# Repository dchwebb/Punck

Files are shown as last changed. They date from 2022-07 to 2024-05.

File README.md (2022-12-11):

# Punck
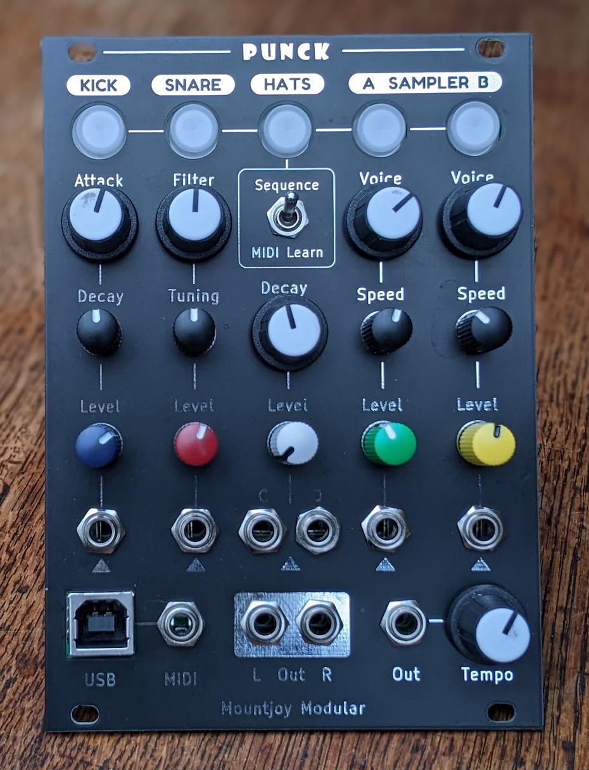
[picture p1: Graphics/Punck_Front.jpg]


Overview
--------

- Audio Demo with Kick, snare and hi hats: [Punck.wav](https://raw.githubusercontent.com/dchwebb/Punck/master/Drum_Sequences/Punck.wav)
- Audio Demo with all voices and samples: [Punck2.wav](https://raw.githubusercontent.com/dchwebb/Punck/master/Drum_Sequences/Punck2.wav)

Punck is drum machine designed for use with Eurorack modular synthesizers. Its five primary voices are Kick, Snare, High Hat and two sample playback channels. In addition Toms and Claps voices are available via MIDI.

It features a built-in drum sequencer with five patterns each with up to 4 bars in length and either 16 or 24 beats per bar.

Voices can be triggered via front panel illuminated buttons, gate input, USB MIDI, serial MIDI and the drum sequencer. All trigger modes are available simultaneously.

Samples are stored on 32MB of internal Flash memory. This storage space is made available as a standard USB drive, requiring no external drives or SD cards.

A browser-based editor allows drum sequences to be entered graphically and detailed parameters of internal voices to be edited. A MIDI mapping facility provides access to different articulations of voices and different samples for the sampler tracks.

Audio DSP
---------

### Kick
The kick drum is modelled on a Roland TR-808 kick. This is generated in five phases, the first three providing an initial steep ramp and discontinuity for the 'click', a fast sine wave at 130Hz and then a slowly decelerating sine wave starting at 60Hz. A potentiometer-controlled 2-pole low pass filter softens the attack and a decay control adjusts the rate at which the level is reduced.

### Snare
The snare is formed of 3 pitched sine wave partials representing the body of the drum and a noise component representing the snare. The partials form the first three modes of vibration of the body. The initial frequency is potentiometer-controlled and the next two partials pitched at multiples of 1.588 and 1.833. The noise component is derived from two random number readings (left and right) and has a decay rate separate from the overall volume envelope. A potentiometer-controlled 2-pole low pass filter attenuates the high frequencies.

### Hi hat
The hi hat consists of 6 square waves with varying rates and levels of frequency modulation. In addition a stereo noise component is used at the beginning of the note. Separate 2-pole high and low pass filters use different ramp envelopes to increase the frequency of the HP filter and reduce the frequency of the LP filter as the note sustains. The decay of the noise and FM partials are separately configurable. When a range of MIDI notes is used to control the hi hat each note will result in a successively more 'open' hi hat sound.

### Sampler A and B
Two independent sample playback voices are provided. These play wave files (8, 16, 24 or 32 bit) stored in the internal flash storage. Each sampler can only play a single sample at a time allowing a maximum of two simultaneously playing voices. Each sampler has a speed control allowing a playback range of 0.5 - 1.5 original speed. Base playback speed is normalised to 48kHz from the original sample rate.

The sample's file name determines the bank (A or B) and index of the sample. Optionally adding suffix '.vNN' to the sample name will set the initial volume of the sample where NN is a value from 0 - 200% and 100% is the original sample level. Eg naming a sample 'B3crash.v150.wav' will make it the 3rd sample on bank B and will play at 150% of its original level.

### Toms
The Toms voice has no UI but is accessible from MIDI and the internal sequencer. An initial fast ramp is followed by a decelerating sine wave. Allocating multiple MIDI notes to playback will allow a range of pitches to be mapped over the MIDI notes.

### Claps
The Claps have no UI but are accessible from MIDI and the internal sequencer. Four 'claps' are played at slightly varying intervals with a sustained phase at the end of the fourth. Each clap is formed of band-pass filtered noise with a center frequency of 1250Hz and a Q of 3.

### Reverb
The reverb engine is derived from Geraint Luff's design: [Signalsmith Audio](https://signalsmith-audio.co.uk/writing/2021/lets-write-a-reverb/). This divides the stereo dry audio into 8 channels which then pass through various diffusion stages followed by a feedback mixer. The diffusion stages use short delay lines and a Hadamard mixing matrix to create a short diffused reverb. The feedback mixer uses longer delays to spread the diffusion channels. The 8 reverb channels are then mixed down to stereo and blended with the dry signal. A 2-pole Low pass filter is used at the input to control high end.

Architecture
------------

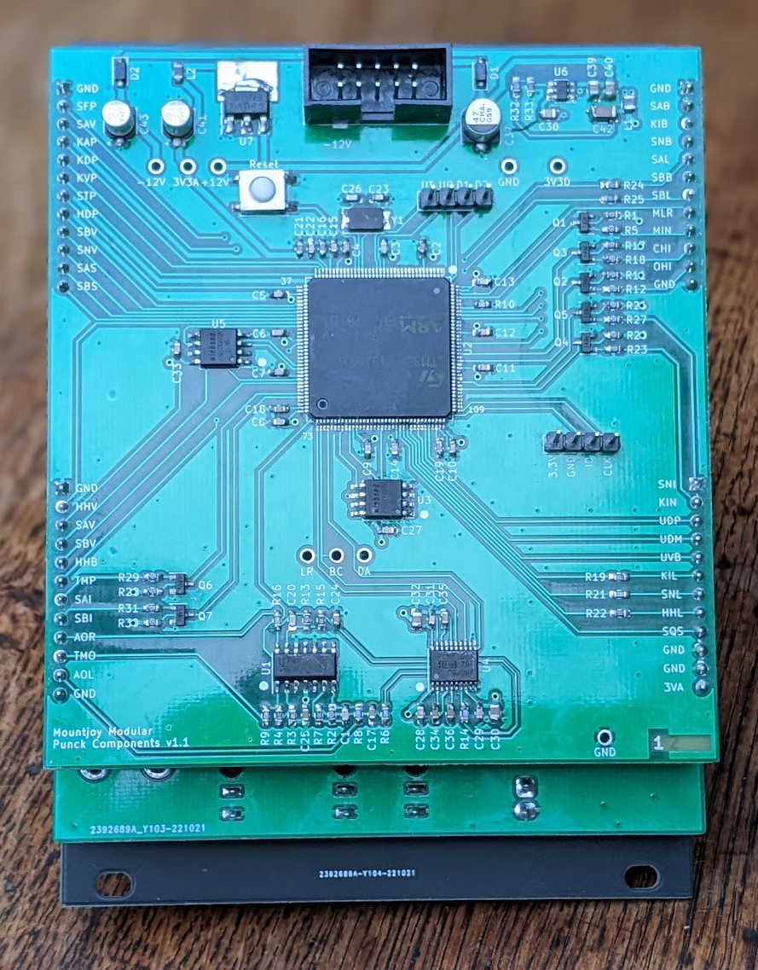
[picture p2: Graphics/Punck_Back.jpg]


### Microcontroller

An STM32H743 microcontroller is responsible for voice generation, USB and MIDI handling, interfacing with the Flash storage devices via QSPI and true random number generation used to generate white noise for various voices. Code is written in C++ 20 using the STM32CubeIDE Eclipse-based IDE. All hardware interfacing is carried out through custom code (ie no STM HAL libraries).

Two internal ADCs read the various potentiometers using DMA circular mode. Timers in PWM mode are used to variably illuminate the LEDs integrated into the push buttons.

An external crystal clocked at 12MHz is scaled using the internal PLL to a main system clock of 400MHz. USB is clocked from the internal 48 MHz RC oscillator.

The microcontroller operates in device mode simultaneously managing three USB classes:

- Mass Storage Class:
Used to provide access to the internal sample flash memory so the storage can be accessed as a normal USB Flash drive. The storage is formatted using FAT16 file system.

- MIDI/Audio Class: 
Bi-directional MIDI is supported to enable playback of drum voices from a USB host. A sysex implementation allows the Browser editor to exchange configuration and playback information with the module.

- Communication Device Class:
A console application is provided to manage and debug the module. This provides information general maintenance tools, configuration options and tools for managing the internal flash storage (formatting, directory listings, disk analysis etc).

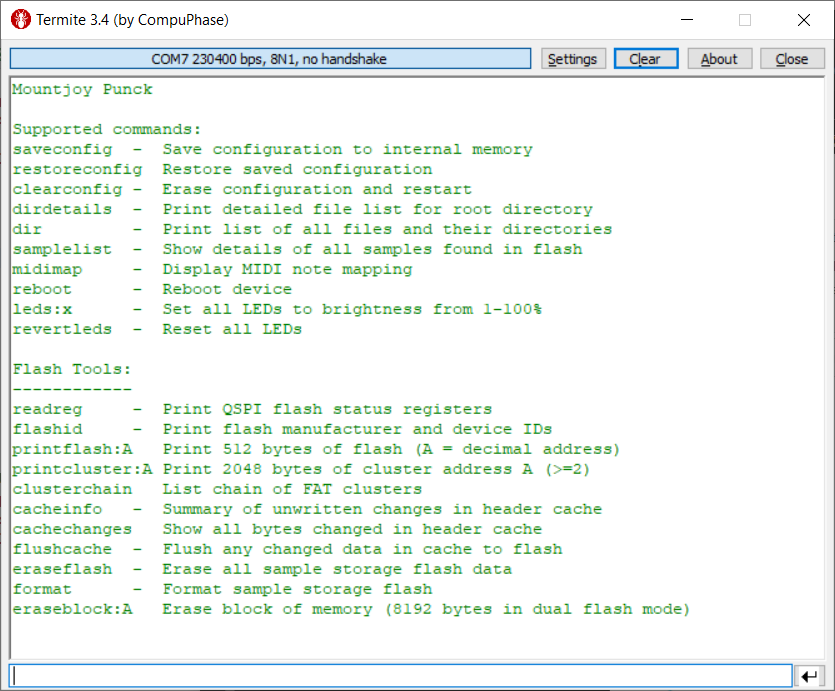
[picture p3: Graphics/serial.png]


### Flash Storage
32MB of internal Flash memory is provided to allow internal sample storage. This consists of two 128Mbit Winbond W25Q128JVS chips connected via QSPI. The MCU operates the flash storage in Dual-flash mode, where 8 bits can be sent/received simultaneously by accessing two Flash memories in parallel. The memory is clocked at ~28MHz.

### Audio DAC
Punck uses a TI PCM5100APW Audio DAC clocked at 48kHz in stereo. The MCU interfaces with the DAC via I2S.

### Audio and Input Conditioning
The stereo audio signal is amplified with a gain of -2.74 using a TL074 op-amp. This also amplifies the tempo clock out signal to around a 5V level. Input clamping is done with MMBT3904 transistors.

### Power Supplies

The Eurorack +/-12V rails have reverse polarity protection and filtering and are then scaled to separate digital and analog 3.3V rails. The 3.3V MCU and DAC digital power supplies are provided by a TI TPS561201 switched-mode synchronous step-down power supply. An LD1117-3.3 linear regulator supplies the analog 3.3V power. A common digital/analog ground plane is used.

- +12V Current Draw: 123mA
- -12V Current Draw: 8mA

Construction
------------

The module is constructed using a sandwich of three PCBs. Schematic and PCB layout carried out in Kicad v6.08.

The component board is a four layer PCB with top mounted components, two inner ground layers and mainly power routing on the bottom layer. 

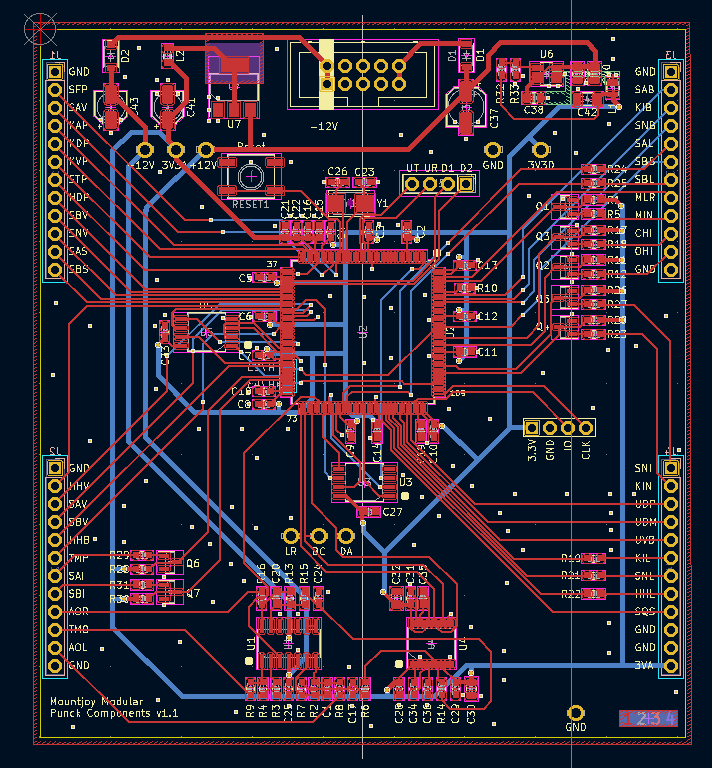
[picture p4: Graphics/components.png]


The control board is a two layer board on which are mounted the jacks, potentiometers, buttons and USB. 

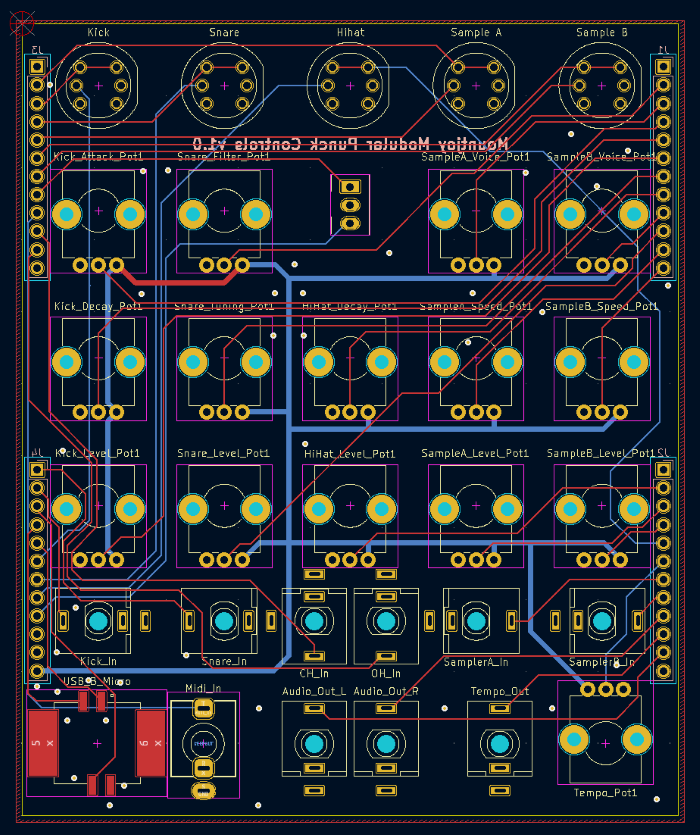
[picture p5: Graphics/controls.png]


The front panel is a two layer black PCB with exposed coated copper labels and marking.

The prototype was hand-soldered in sections to test each part of the hardware in isolation. This picture shows the power supplies (right), microcontroller (center) and two flash chips (above and to the left of the MCU). The audio DAC and op-amp will be placed on the left hand side:

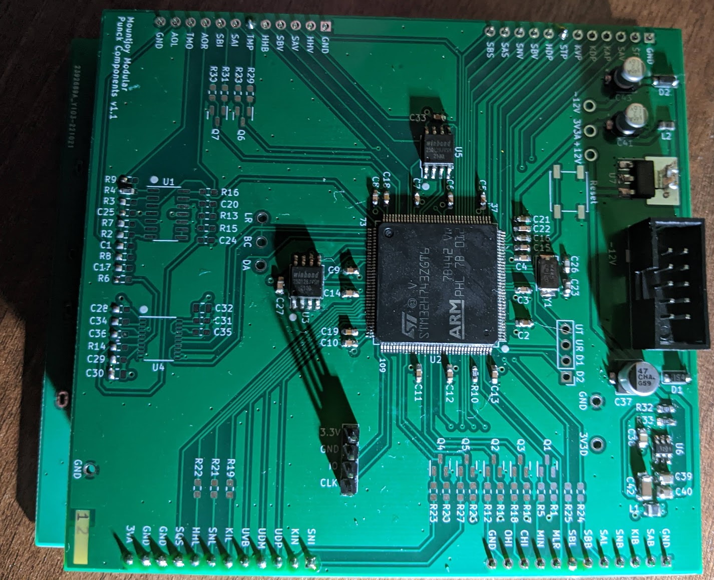
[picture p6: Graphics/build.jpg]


Web Editor
----------

A Chrome-based web editor allows editing of the 5 internal drum sequences:

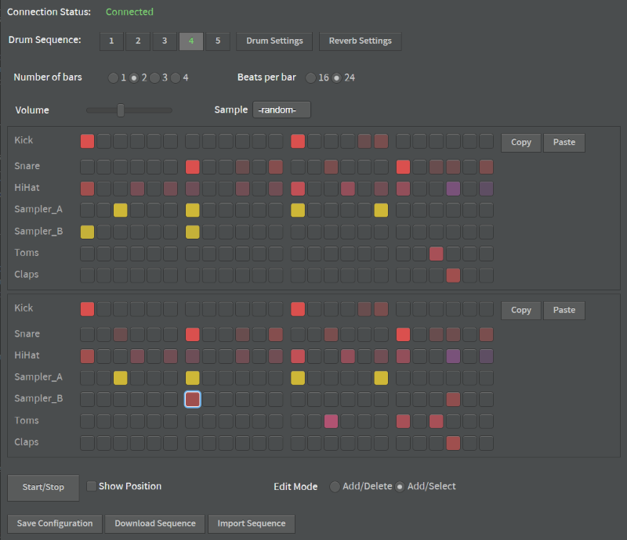
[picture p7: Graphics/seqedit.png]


Each sequence can be up to 4 bars long with either 16 or 24 steps per bar. The level of each hit can be set and voice specific settings applied (eg choosing sample, snare sustain, hi-hat open/closed amount, tom pitch). Drum sequences can be exported and imported as json files.
Playback start/stop and sequence selection can be controlled from the editor.

Internal drum voice and reverb settings can also be edited:

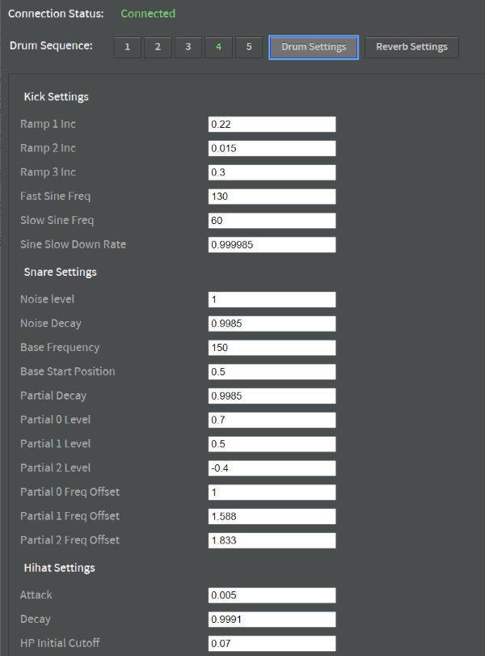
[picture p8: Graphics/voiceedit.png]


Prototype
---------

Development was done on an STM Nucleo development board with external surface mount ICs (flash, DAC) soldered to breakout boards for prototyping:

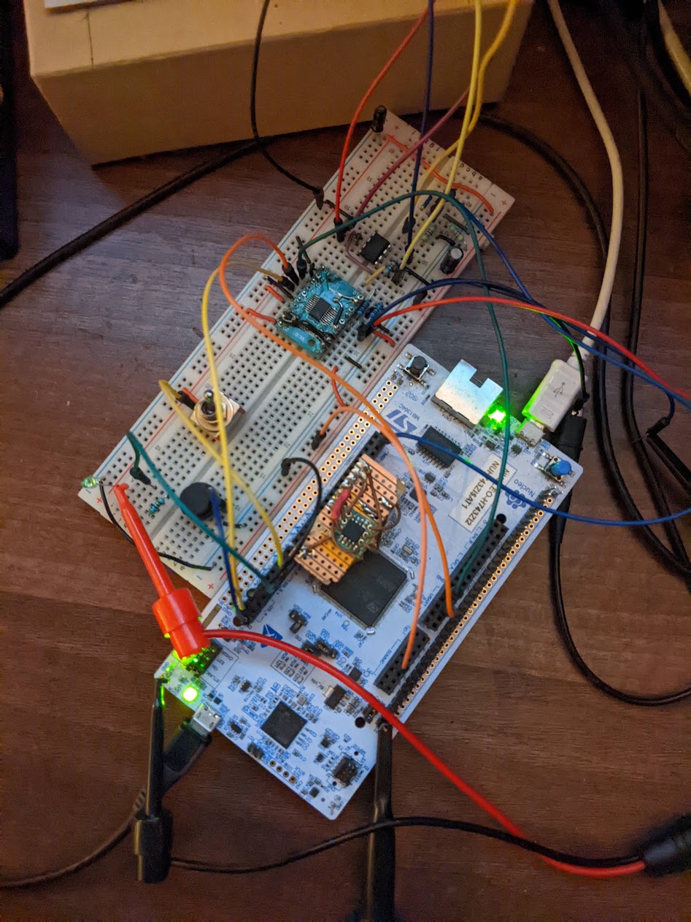
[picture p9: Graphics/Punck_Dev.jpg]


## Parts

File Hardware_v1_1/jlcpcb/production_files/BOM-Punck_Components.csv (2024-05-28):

Comment | Designator | Footprint | LCSC
L | L2 | L_0805_2012Metric | C1015
STM32H743ZITx | U2 | LQFP-144_20x20mm_P0.5mm | C114408
PCM5100APW | U4 | SSOP-20_4.4x6.5mm_Pitch0.65mm_Round_Pads | C131154
TPS561201 | U6 | SOT-23-6_Handsoldering | C133965
100nF | C10,C11,C12,C13,C14,C15,C22,C27,C28,C29,C3,C31,C33,C35,C4,C5,C6,C7,C8,C9 | C_0603_1608Metric_Pad1.08x0.95mm_HandSolder | C14663
100pF | C1,C20 | C_0603_1608Metric_Pad1.08x0.95mm_HandSolder | C14858
1uF | C16,C21 | C_0603_1608Metric_Pad1.08x0.95mm_HandSolder | C15849
2n2 | C17,C24 | C_0603_1608Metric_Pad1.08x0.95mm_HandSolder | C1604
30pF | C23,C26 | C_0603_1608Metric_Pad1.08x0.95mm_HandSolder | C1658
47uF | C37,C41,C43 | CP_Elec_5x5.8 | C178597
4.7uF | C2 | C_0603_1608Metric_Pad1.08x0.95mm_HandSolder | C19666
MMBT3904 | Q1,Q2,Q3,Q4,Q5,Q6,Q7 | SOT-23 | C20526
1k | R14,R16,R6,R8,R9 | R_0603_1608Metric_Pad0.98x0.95mm_HandSolder | C21190
15k | R15,R3,R7 | R_0603_1608Metric_Pad0.98x0.95mm_HandSolder | C22809
4k7 | R1,R11,R12,R17,R18,R20,R23,R26,R27,R28,R29,R30,R31,R5 | R_0603_1608Metric_Pad0.98x0.95mm_HandSolder | C23162
560 | R19,R21,R22,R24,R25 | R_0603_1608Metric_Pad0.98x0.95mm_HandSolder | C23204
2.2uF | C18,C19,C25,C34,C36 | C_0603_1608Metric_Pad1.08x0.95mm_HandSolder | C23630
100k | R10 | R_0603_1608Metric | C25803
10k | R33,R4 | R_0603_1608Metric_Pad0.98x0.95mm_HandSolder | C25804
47k | R13,R2 | R_0603_1608Metric_Pad0.98x0.95mm_HandSolder | C25819
100nF | C38 | R_0805_2012Metric | C28233
33k | R32 | R_0603_1608Metric_Pad0.98x0.95mm_HandSolder | C4216
10uF | C30,C32,C39,C40 | C_0805_2012Metric | C440198
12MHz 20pF | Y1 | Crystal_SMD_5032-2Pin_5.0x3.2mm | C479171
LD1117-3.3-4Tab | U7 | SOT-223-3_TabPin2 | C6186
TL074 | U1 | SOIC-14_3.9x8.7mm_P1.27mm | C6963
1N5819 | D1,D2 | D_SOD-123 | C8598
47uF | C42 | R_1206_3216Metric | C96123
W25Q128JVS | U3,U5 | SOIC-8_5.23x5.23mm_P1.27mm | C97521
3.3uH | L1 | L_0806 | C98336

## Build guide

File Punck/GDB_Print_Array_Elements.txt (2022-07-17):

In CubeIDE Debugger Console :

#Allow unlimited number of elements to be printed:
set print elements 0

# Prevent <repeats XXX times> messages in print out
set print repeats 0

# Print 10000 elements from array 'buffer' in hex format
print /x *buffer@5000

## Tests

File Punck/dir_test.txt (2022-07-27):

  Attrib Cluster  Bytes    Created   Accessed Name          Clusters
  ------------------------------------------------------------------
  LFN  2                                       Information   [0x72]
  LFN  1                                      System Volume  [0x72]
  -HSD-        2      0   0/0/1980   0/0/1980 SYSTEM~1      
> ---D-        2      0  23/7/2022  23/7/2022 .             
> ---D-        0      0  23/7/2022  23/7/2022 ..            
> LFN  2                                      Guid           [0xff]
> LFN  1                                      IndexerVolume  [0xff]
> ----A        3     76  23/7/2022  27/7/2022 INDEXE~1.     
> LFN  2                                      t              [0xce]
> LFN  1                                      WPSettings.da  [0xce]
> ----A     1296     12  24/7/2022  27/7/2022 WPSETT~1DAT   
  ----A        4   4615  23/7/2022  23/7/2022 TWOBLK.TXT    4-6
  ----A        7   4615  23/7/2022  23/7/2022 THREE.TXT     7-9
  *Del*       10 249022  23/7/2022  23/7/2022 åRUM02.WAV    
  *Del*       10 249022  23/7/2022  23/7/2022 åRUM03.WAV    
  LFN 165                                      Drums04.wav    [0xca]
  *Del*      132 270670  23/7/2022  23/7/2022 åRUMS04.WAV   
  *Del*      265 249022  23/7/2022  23/7/2022 åRUM05.WAV    
  *Del*      387 270670  23/7/2022  23/7/2022 åRUMS06.WAV   
  *Del*      520 249022  23/7/2022  23/7/2022 åRUM07.WAV    
  *Del*      642 270670  23/7/2022  23/7/2022 åRUMS08.WAV   
  *Del*      775 249022  23/7/2022  23/7/2022 åRUM09.WAV    
  *Del*      897 270670  23/7/2022  23/7/2022 åRUMS10.WAV   
  *Del*     1030 249022  23/7/2022  23/7/2022 åRUM11.WAV    
  *Del*     1152 270670  23/7/2022  23/7/2022 åRUMS12.WAV   
  *Del*     1285 249022  23/7/2022  23/7/2022 åRUM13.WAV    
  *Del*     1407 270670  23/7/2022  23/7/2022 åRUMS14.WAV   
  *Del*     1540 249022  23/7/2022  23/7/2022 åRUM15.WAV    
  *Del*       10 270670  23/7/2022  23/7/2022 åRUM01.WAV    
  *Del*      143 249022  23/7/2022  23/7/2022 åRUM02.WAV    
  *Del*      265 270670  23/7/2022  23/7/2022 åRUM03.WAV    
  *Del*      398 270670  23/7/2022  23/7/2022 åRUM04.WAV    
  *Del*      531 249022  23/7/2022  23/7/2022 åRUM05.WAV    
  *Del*      653 270670  23/7/2022  23/7/2022 åRUM06.WAV    
  *Del*      786 249022  23/7/2022  23/7/2022 åRUM07.WAV    
  *Del*      908 270670  23/7/2022  23/7/2022 åRUM08.WAV    
  *Del*     1041 249022  23/7/2022  23/7/2022 åRUM09.WAV    
  *Del*     1163 270670  23/7/2022  23/7/2022 åRUM10.WAV    
  *Del*     1296   2048  23/7/2022  23/7/2022 å293203_      
> -H--A        0      0   0/0/1980   0/0/1980 [0C]             
  *Del*     1297 249022  24/7/2022  24/7/2022 åRUM11.WAV    
  *Del*     1419 270670  24/7/2022  24/7/2022 åRUM12.WAV    
  *Del*     1552 249022  24/7/2022  24/7/2022 åRUM13.WAV    
  *Del*     1674 270670  24/7/2022  24/7/2022 åRUM14.WAV    
  *Del*     1807 249022  24/7/2022  24/7/2022 åRUM15.WAV    
  *Del*     1929 270670  24/7/2022  24/7/2022 åRUM16.WAV    
  *Del*     2062 249022  24/7/2022  24/7/2022 åRUM17.WAV    
  *Del*     2184 270670  24/7/2022  24/7/2022 åRUM18.WAV    
  *Del*     2317 249022  24/7/2022  24/7/2022 åRUM19.WAV    
  *Del*     2439 270670  25/7/2022  25/7/2022 åRUM20.WAV    
  *Del*     2572 249022  25/7/2022  25/7/2022 åRUM21.WAV    
  *Del*     2694 270670  25/7/2022  25/7/2022 åRUM22.WAV    
  *Del*       10 249022  25/7/2022  25/7/2022 åRUM23.WAV    
  *Del*     2827 270670  25/7/2022  25/7/2022 åRUM24.WAV    
  *Del*     2960 249022  25/7/2022  25/7/2022 åRUM25.WAV    
  *Del*     3082 270670  25/7/2022  25/7/2022 åRUM26.WAV    
  ----A     3215 249022  25/7/2022  25/7/2022 DRUM27.WAV    3215-3336
  ----A     3337 270670  25/7/2022  25/7/2022 DRUM28.WAV    3337-3469
  ----A     3470 249022  25/7/2022  25/7/2022 DRUM29.WAV    3470-3591
  ----A     3592 270670  25/7/2022  25/7/2022 DRUM30.WAV    3592-3724
  ----A     3725 249022  25/7/2022  25/7/2022 DRUM31.WAV    3725-3846
  ----A     3847 270670  25/7/2022  25/7/2022 DRUM32.WAV    3847-3979
  ----A     3980 249022  25/7/2022  25/7/2022 DRUM33.WAV    3980-4101
  ----A     4102 270670  25/7/2022  25/7/2022 DRUM34.WAV    4102-4234
  ----A     4235 249022  25/7/2022  25/7/2022 DRUM35.WAV    4235-4356
  ----A     4357 270670  25/7/2022  25/7/2022 DRUM36.WAV    4357-4489
  ----A     4490 249022  25/7/2022  25/7/2022 DRUM37.WAV    4490-4611
  ----A     4612 270670  25/7/2022  25/7/2022 DRUM38.WAV    4612-4744
  *Del*     4745 249022  25/7/2022  25/7/2022 åRUM39.WAV    
  ----A     4867 270670  25/7/2022  25/7/2022 DRUM40.WAV    4867-4999
  ----A     5000 249022  25/7/2022  25/7/2022 DRUM41.WAV    5000-5121
  ----A      132  27226  26/7/2022  26/7/2022 SNARE.WAV     132-145
  ----A      146  73084  26/7/2022  26/7/2022 TAMB.WAV      146-181
  ----A      182 270670  26/7/2022  26/7/2022 DRUM42.WAV    182-314
  ----A      315 249022  26/7/2022  26/7/2022 DRUM43.WAV    315-436
  ----A      437 270670  26/7/2022  26/7/2022 DRUM44.WAV    437-569
  ----A      570 249022  26/7/2022  26/7/2022 DRUM45.WAV    570-691

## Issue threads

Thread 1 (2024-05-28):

Punck PCBs ?

modulove, 2024-05-28:
Hi there, this is an impressive project, thanks for sharing!

Any chance someone has spare PCBs left ?
Ideally I would want to make me a few of these with components placed already but dont know if this is feasible for me.

Would be nice to give this a try, need some Drums for my development case.

Kind Regards
Linus

dchwebb, 2024-05-28:
Linus

I do have some spare sets of PCBs, but none with components on. If you are happy with reasonably advanced SMD soldering (the microcontroller has 144 pins) then you are welcome to have a set.

Otherwise you could get the component board assembled at JLC PCB – they do a minimum assembly of 2 pieces and are fairly reasonably priced. I’ve had a quick look and they do have the microcontroller and flash chips in stock.

Dominic

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

modulove, 2024-05-28:
Thanks for your answer.

I think this would be to much for me, I just did the first basic steps in SMD soldering.

I would like to order two of them but could only find the position file but not the BOM in the Hardware folder.

Will pop into KiCad to see if I can export the BOM and see if JLCPCB will work.

Thanks for sharing this, looks very nice!
Linus

dchwebb, 2024-05-28:
If you are getting them assembled by JLC then the easiest thing is to use this plug-in in Kicad to assign the appropriate parts:

https://github.com/bouni/kicad-jlcpcb-tools

If I have some time later I can try and go through and assign the appropriate parts.

Dominic

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

dchwebb, 2024-05-28:
Linus

I’ve updated the Git project with some JLC assembly data:

https://github.com/dchwebb/Punck/tree/main/Hardware_v1_1/jlcpcb

They didn’t have any suitable crystals so you would need to source and solder those separately (or a minor firmware change would be needed to support a different frequency crystal).

You would also need to hand solder the headers and connectors.

I haven’t checked everything thoroughly so I would do that before ordering. It looks like the cost of 2 component boards with assembly would be around £40 – though check for any coupons as they usually offer discounts.

Dominic

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

dchwebb, 2024-05-28:
Actually I’ve just checked the firmware and it looks as if I couldn’t find 8MHz crystals either, and changed it to use 12MHz crystals which are in stock at JLC. I have amended the production files accordingly.

dchwebb, 2024-05-28:
You will need an STLink programmer. A lot of the ones out there are knock-offs and don't use STM chips so are not always reliable. One way of getting a reasonably cheap programmer is to find a second-hand Nucleo development board as these all have STLinks built in. Once you have a working programmer you program the chip using the STM32CubeProgrammer software.

When you get to that stage I can provide you with a binary and more detailed instructions.

modulove, 2024-05-30:
Thanks for the explanation. Got everything collected and will order soon! Excited to get these running :)

dchwebb, 2024-11-27:
You connect the programmer to the pin header to the right of the PCB marked '3.3v GND IO CLK'. Connect them to the corresponding pins on your programmer - 'IO' and 'CLK' may be marked 'SWDIO' and 'SWCLK' depending on which programmer you have.

You then start the STM32CubeProgrammer software (you can download this from ST's website) and at the top right you should have a green button marked 'Connect'. Click that and you should hopefully be able to connect to the microcontroller.

modulove, 2024-11-27:
Thank you!

It worked straight away and I am impressed how the whole experience was.
Very straightforward and solid build.

Will share the modules from this order with my team and want to thank you again for making it happen.

Now to explore the Punck in depth :)

Cheers
Linus

dchwebb, 2024-11-28:
Great news - I hope you enjoy it. Let me know if you need any help using it. You also have some sound editing and drum sequence options available using the web editor tool if you fancy having a play ...

modulove, 2024-11-28:
Thanks! For sure I will check this out. Lovely Kit and package with all the bells and whistles 👍🏼

dchwebb, 2024-11-29:
What operating system are you using? I use Windows and don't have access to a Mac so haven't tested it on that platform (but can have a go at doing some trouble shooting if that is what you are using).

modulove, 2024-11-29:
> What operating system are you using? I use Windows and don't have access to a Mac so haven't tested it on that platform (but can have a go at doing some trouble shooting if that is what you are using).

I'm on Windows 10. Everything is good now and i'm having a blast! Thank you.

modulove, 2025-01-06:
Happy New Year! Just wanted to report back.

We had build and been using the Punck module for some time now and it's big fun!
Thanks you for your help and guidance, it worked quite well at the first try.

Now to decide what to build next from your awesome modules :)

Closed 2025-01-06.

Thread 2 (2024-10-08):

Firmware

KeenVox, 2024-10-08:
Hi,

love the Punck and just received my assembled boards from JLCPCB.  Is there a precompiled binary to flash the stm32?

I'm not really good in coding and not aware how to compile code for stm32 microcontrollers. I have a st-link and did flash stm32 microcontrollers but always with a precompiled binary.

Thx!

dchwebb, 2024-10-09:
I've just added it here: [Punk.elf](https://github.com/dchwebb/Punck/tree/main/Punck/Debug)
After you have flashed the firmware, I recommend connecting to the serial console over USB and issuing the 'format' command to format the internal flash storage to the format used by Punck - don't let the OS do the disk formatting as the module won't recognise if. Once formatted you can copy drum samples over using the module as a USB drive.
I hope it all works - give me a shout if not and you need assistance.
Dom

KeenVox, 2024-10-09:
Thank you very much!

Format like I would format an USB-drive? Or do I need to send it over a terminal or the ST-Link?

dchwebb, 2024-10-09:
When you connect the module via USB it provides various USB classes - MIDI, USB storage and Serial. The serial class allows you to connect a serial terminal application (eg on Windows you can use Termite or Putty). When connected use 'help' to show the various commands available. One command is 'format' which formats the internal storage to FAT16. There is a bit more info and a screenshot of the terminal running in Termite on teh readme.

KeenVox, 2024-12-27:
Hi again,

did finally finish the Punck modul. Sadly I have some problems with sample playback. I did format the internal storage. Put my sampe called A3drum.wav on there and everytime I press the sample A button the system seems to crash as the other three buttons don't react anymore. Anything I'm missing?

dchwebb, 2024-12-27:
Firstly, you need to format the drive using the serial console with the 'format' command. Also the drum sample needs to be mono. If that doesn't help I suggest providing the sample and I can see if I can replicate the issue.

KeenVox, 2024-12-27:
Ah, that may be the problem. The sample is a stereo sample. Will try with mono again.

Strangely when I put two stereo files "A1" and "A2" on it, it also works and plays the files without crashing.
But when you turn the "voice" pot it duplicates the samples after 12 o'clock. Maybe the stereo files are the cause here too?

dchwebb, 2024-12-27:
I've just checked the code and I am wrong - it does support stereo samples. The crash could be caused by an alignment issue in the sample file. If you access the serial console and use the command 'samplelist' you will get a list of the internal storage's sample details. I think it only works if the address field is an even number - ie the last digit 0, 2, 4, 8, A, C, E (or possibly a multiple of four in which case 0, 4, 8, C). This is because we play the sample back directly from the internal flash storage, and if the sample address is not aligned either to a 16 or 32 bit boundary it throws a memory error.

If that is the case and you can supply me the dodgy sample I can look at handling it more gracefully.

The last position in the voice pot is a random mode, so that could be the reason for the apparent duplication.

KeenVox, 2024-12-28:
This is the serial motor output

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

But I it seems I found the problem. It only crashes, if there is only one file per bank and when I dial the pot beyond 12 o'clock.
As soon as there is another file e.g. "A2" it all works like intended. Same for Bank B.
Maybe there is a software conflict when it only finds one file and tries to look for another one, when the pot is turned to the second file?

KeenVox, 2025-01-10:
Punck working too now, as it should.

Had to add an optocoupler for midi like for the Oscar module.

Needed to add at least to samples for A and B after that no more crashes.

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

dchwebb, 2025-01-11:
Great news. I'm just finishing off some PCBs for manufacture, but will get a fix for the sample issue in a week or two.

KeenVox, 2025-01-11:
No worrys, looking forward for the software fixes. In the meantime I'm working on the Ampelope :-D

KeenVox, 2025-03-02:
Hey Dom,

did you find time to look in the samle issue? :)

dchwebb, 2025-03-03:
Sorry - totally forgot. I've just fixed it and the new elf file should work with just one sample in a bank.

KeenVox, 2025-03-08:
Great! Thank you so much!

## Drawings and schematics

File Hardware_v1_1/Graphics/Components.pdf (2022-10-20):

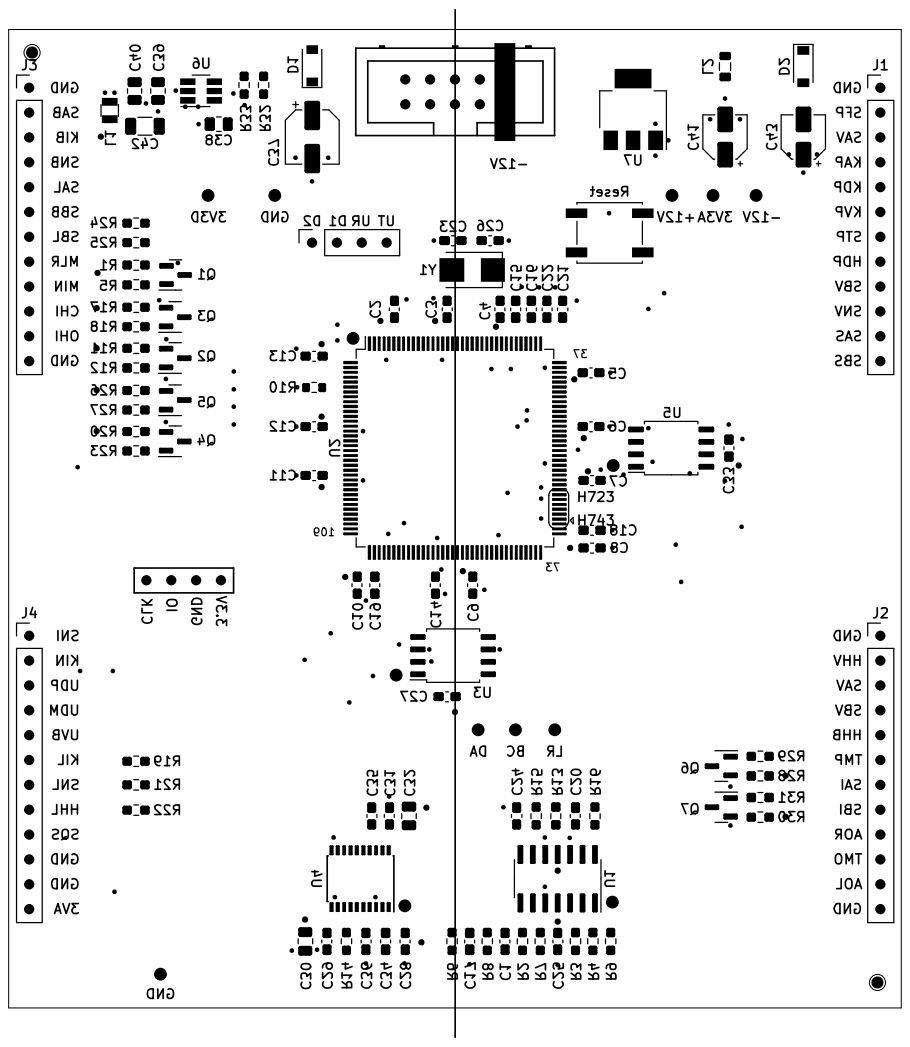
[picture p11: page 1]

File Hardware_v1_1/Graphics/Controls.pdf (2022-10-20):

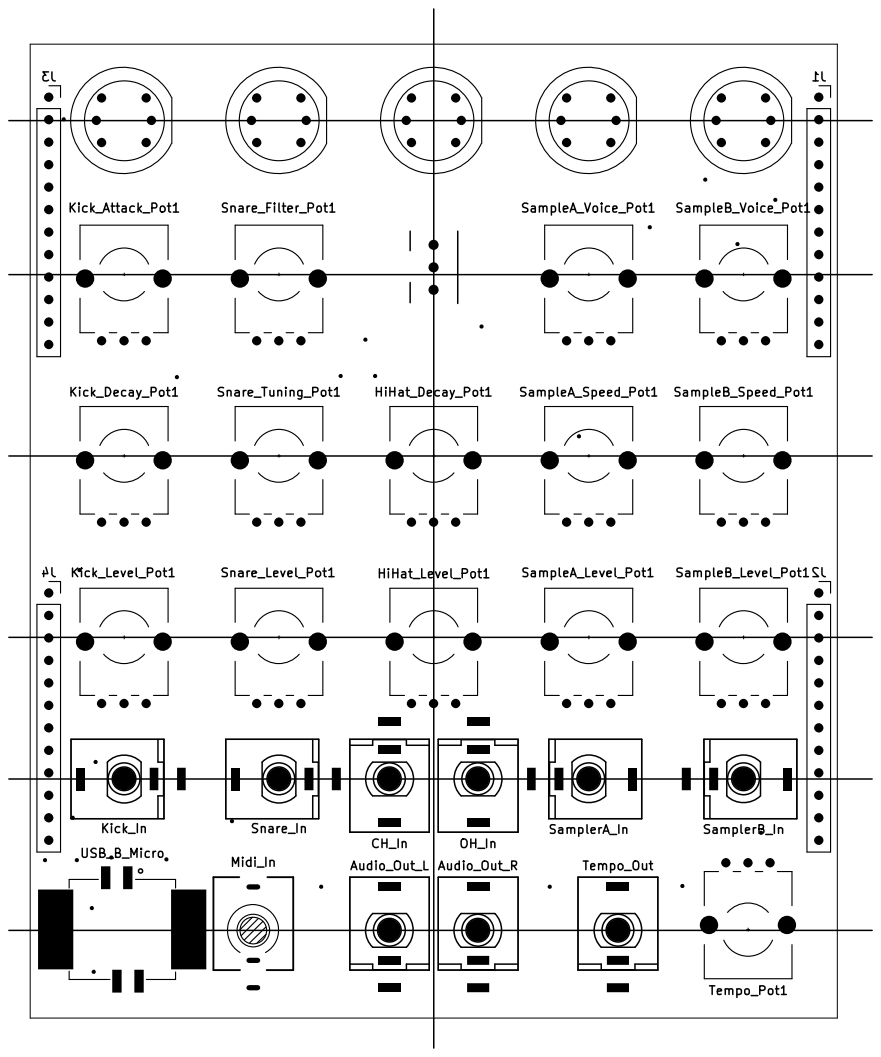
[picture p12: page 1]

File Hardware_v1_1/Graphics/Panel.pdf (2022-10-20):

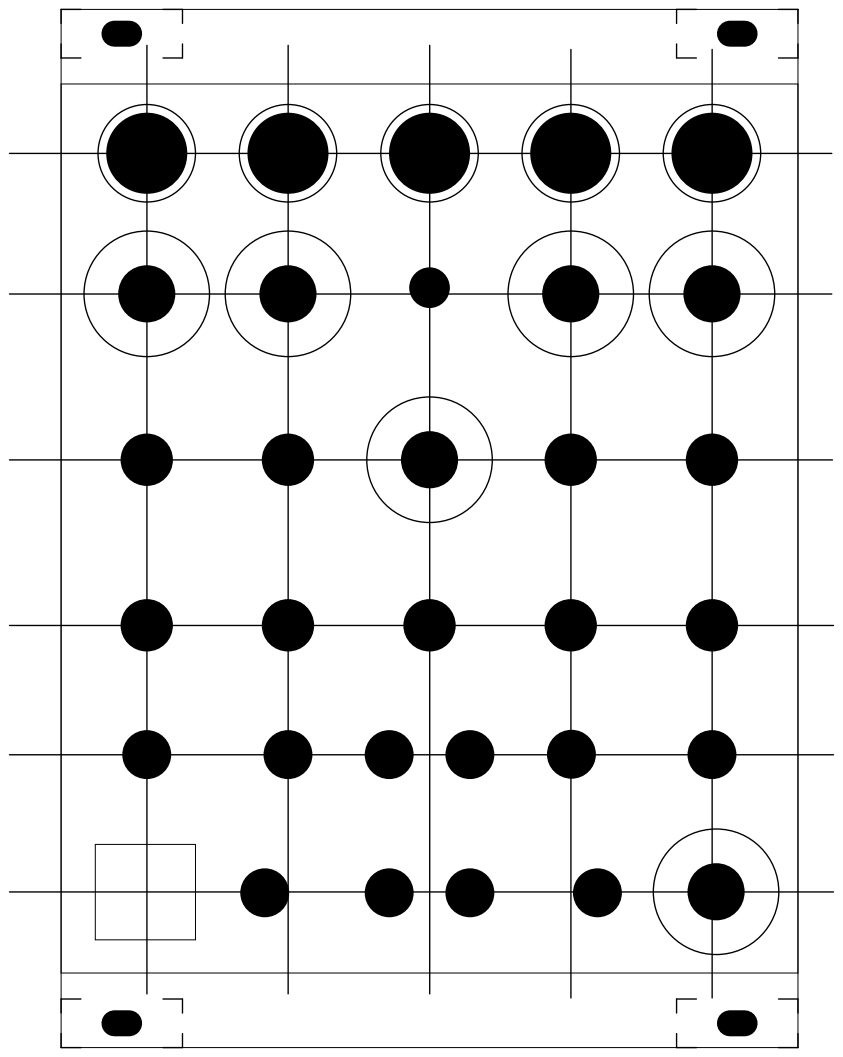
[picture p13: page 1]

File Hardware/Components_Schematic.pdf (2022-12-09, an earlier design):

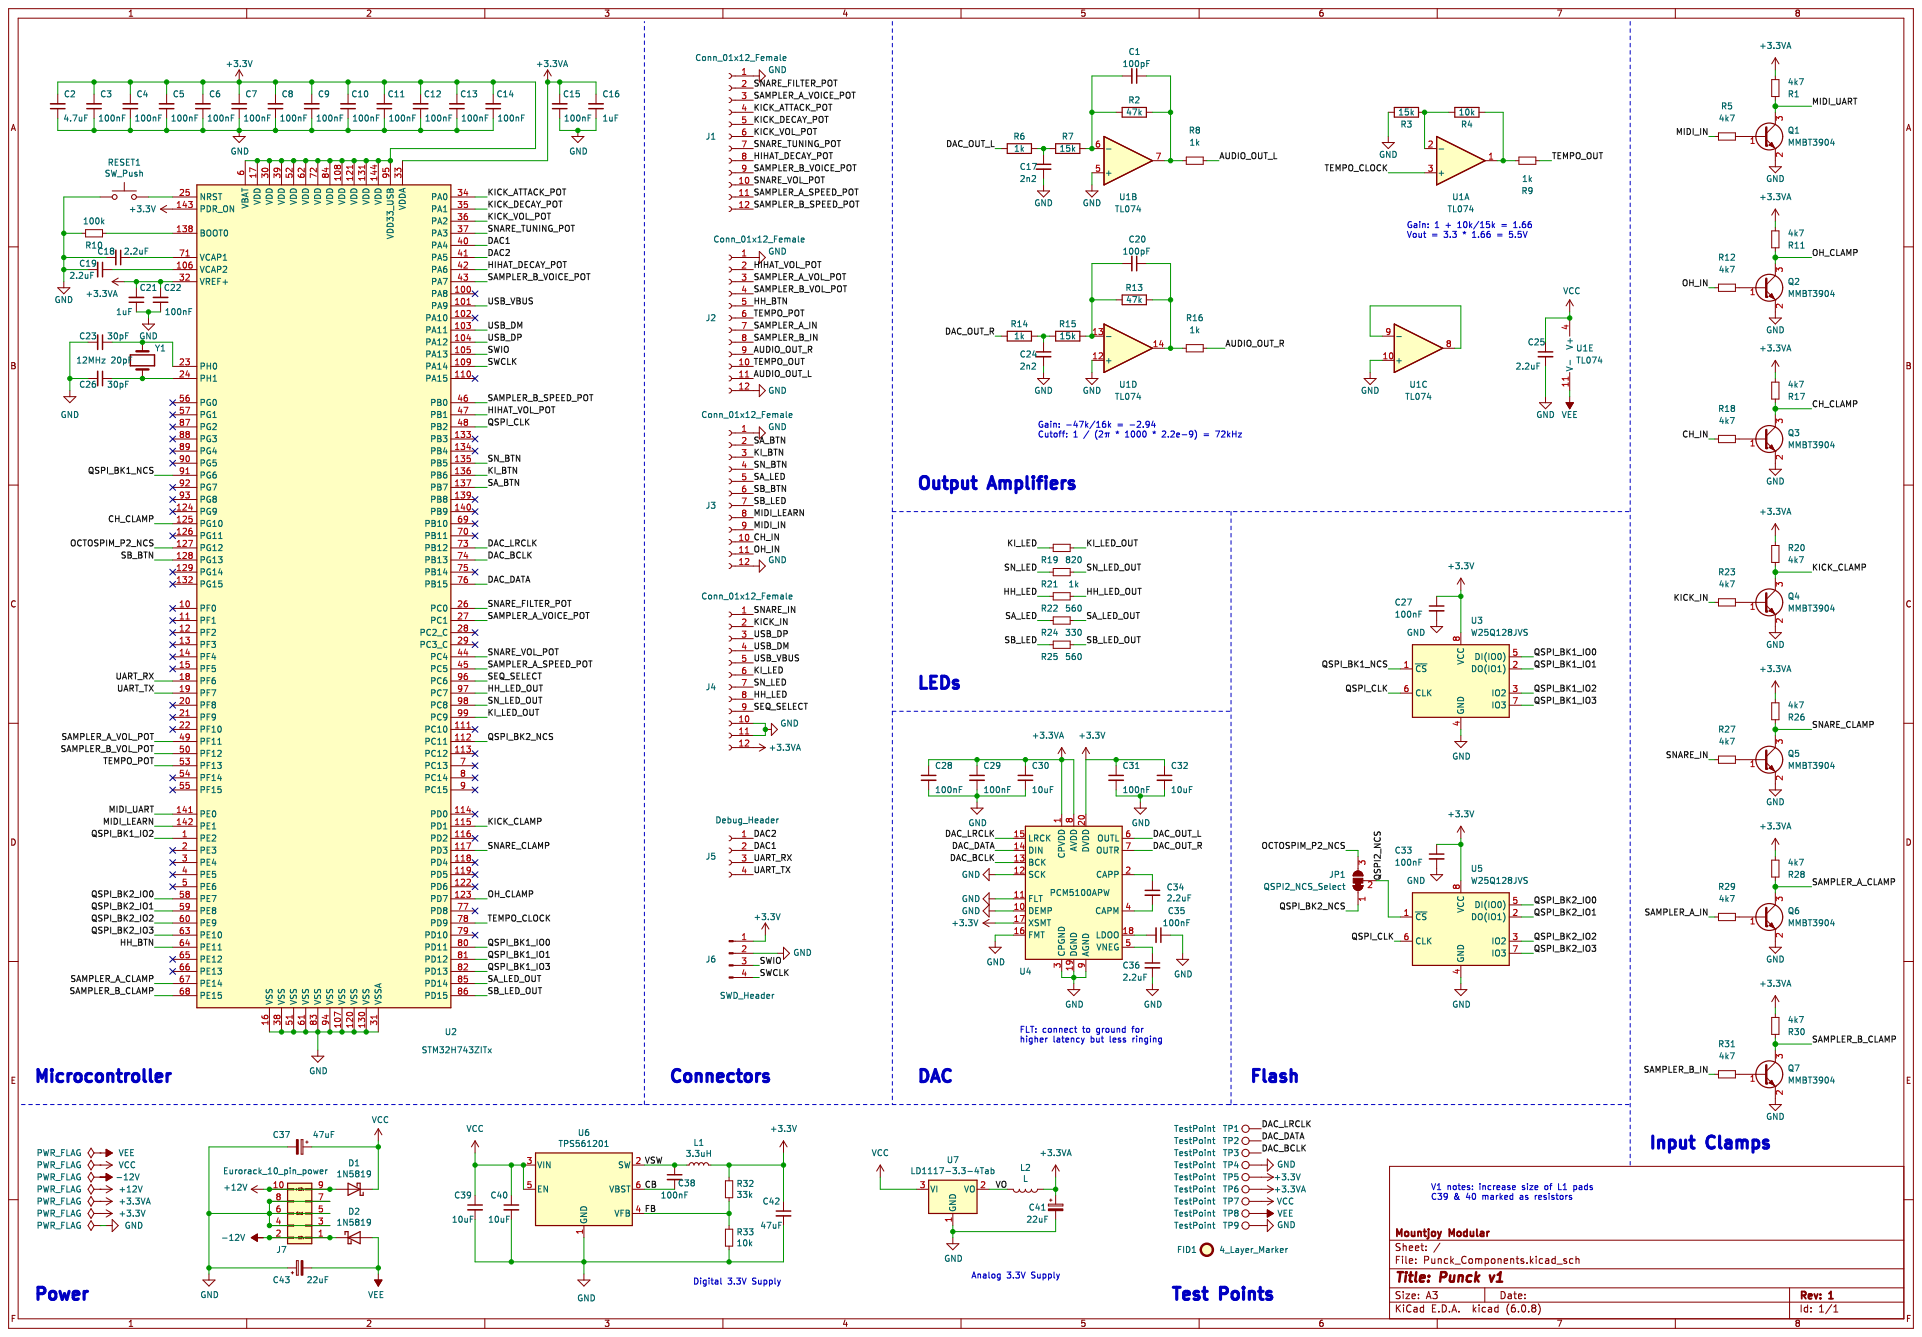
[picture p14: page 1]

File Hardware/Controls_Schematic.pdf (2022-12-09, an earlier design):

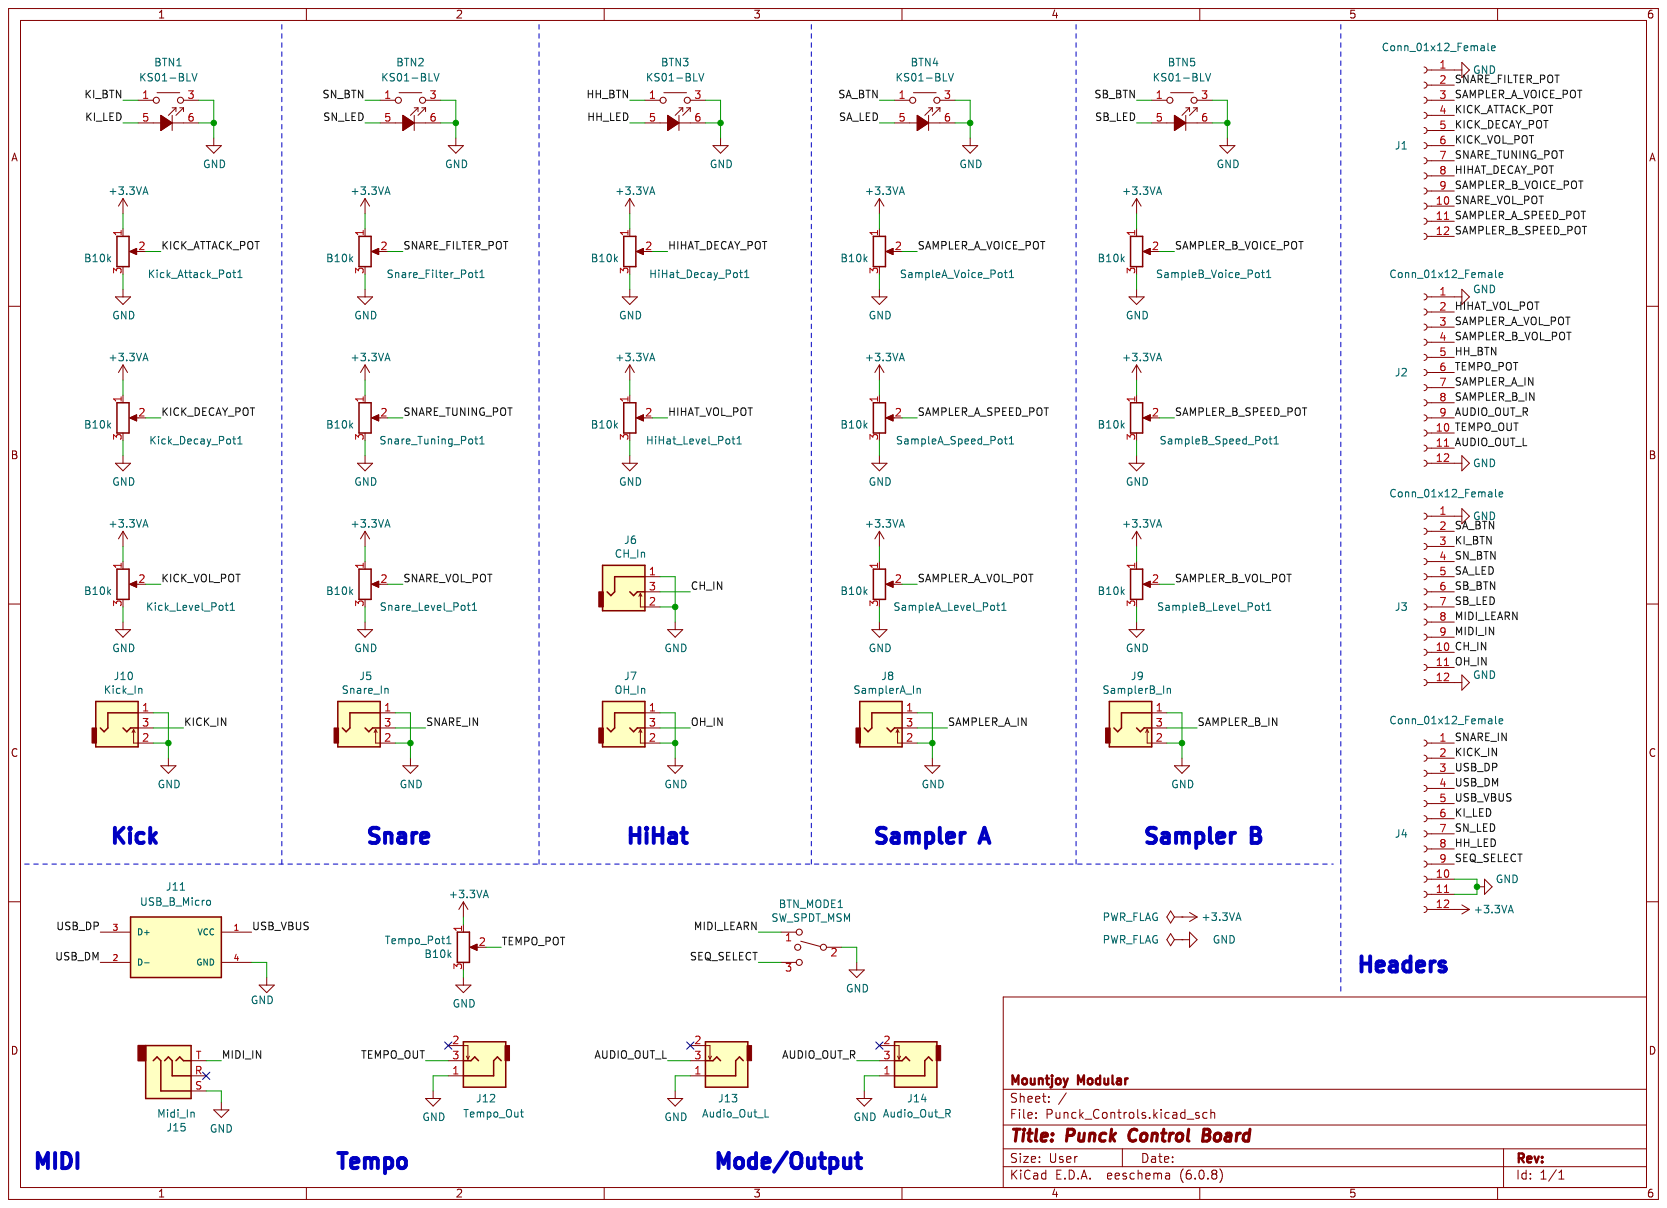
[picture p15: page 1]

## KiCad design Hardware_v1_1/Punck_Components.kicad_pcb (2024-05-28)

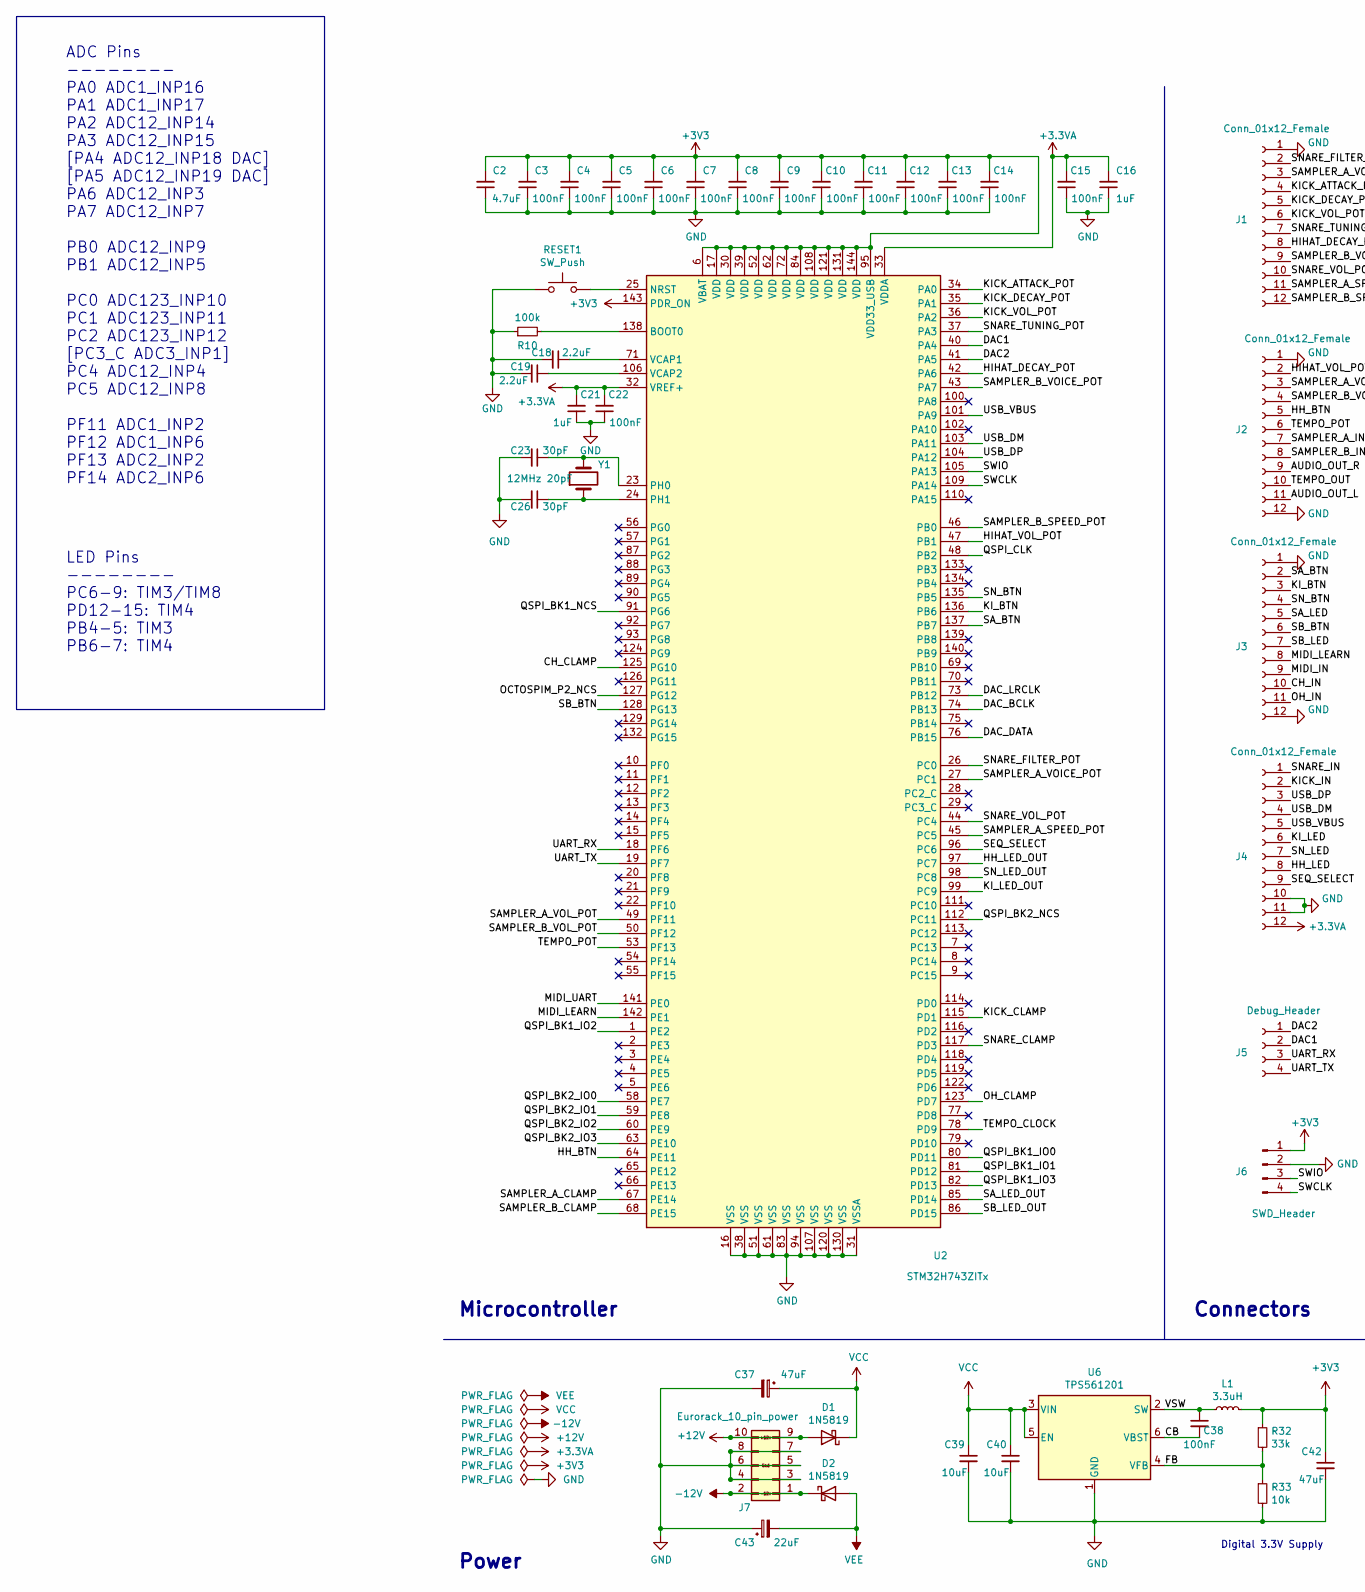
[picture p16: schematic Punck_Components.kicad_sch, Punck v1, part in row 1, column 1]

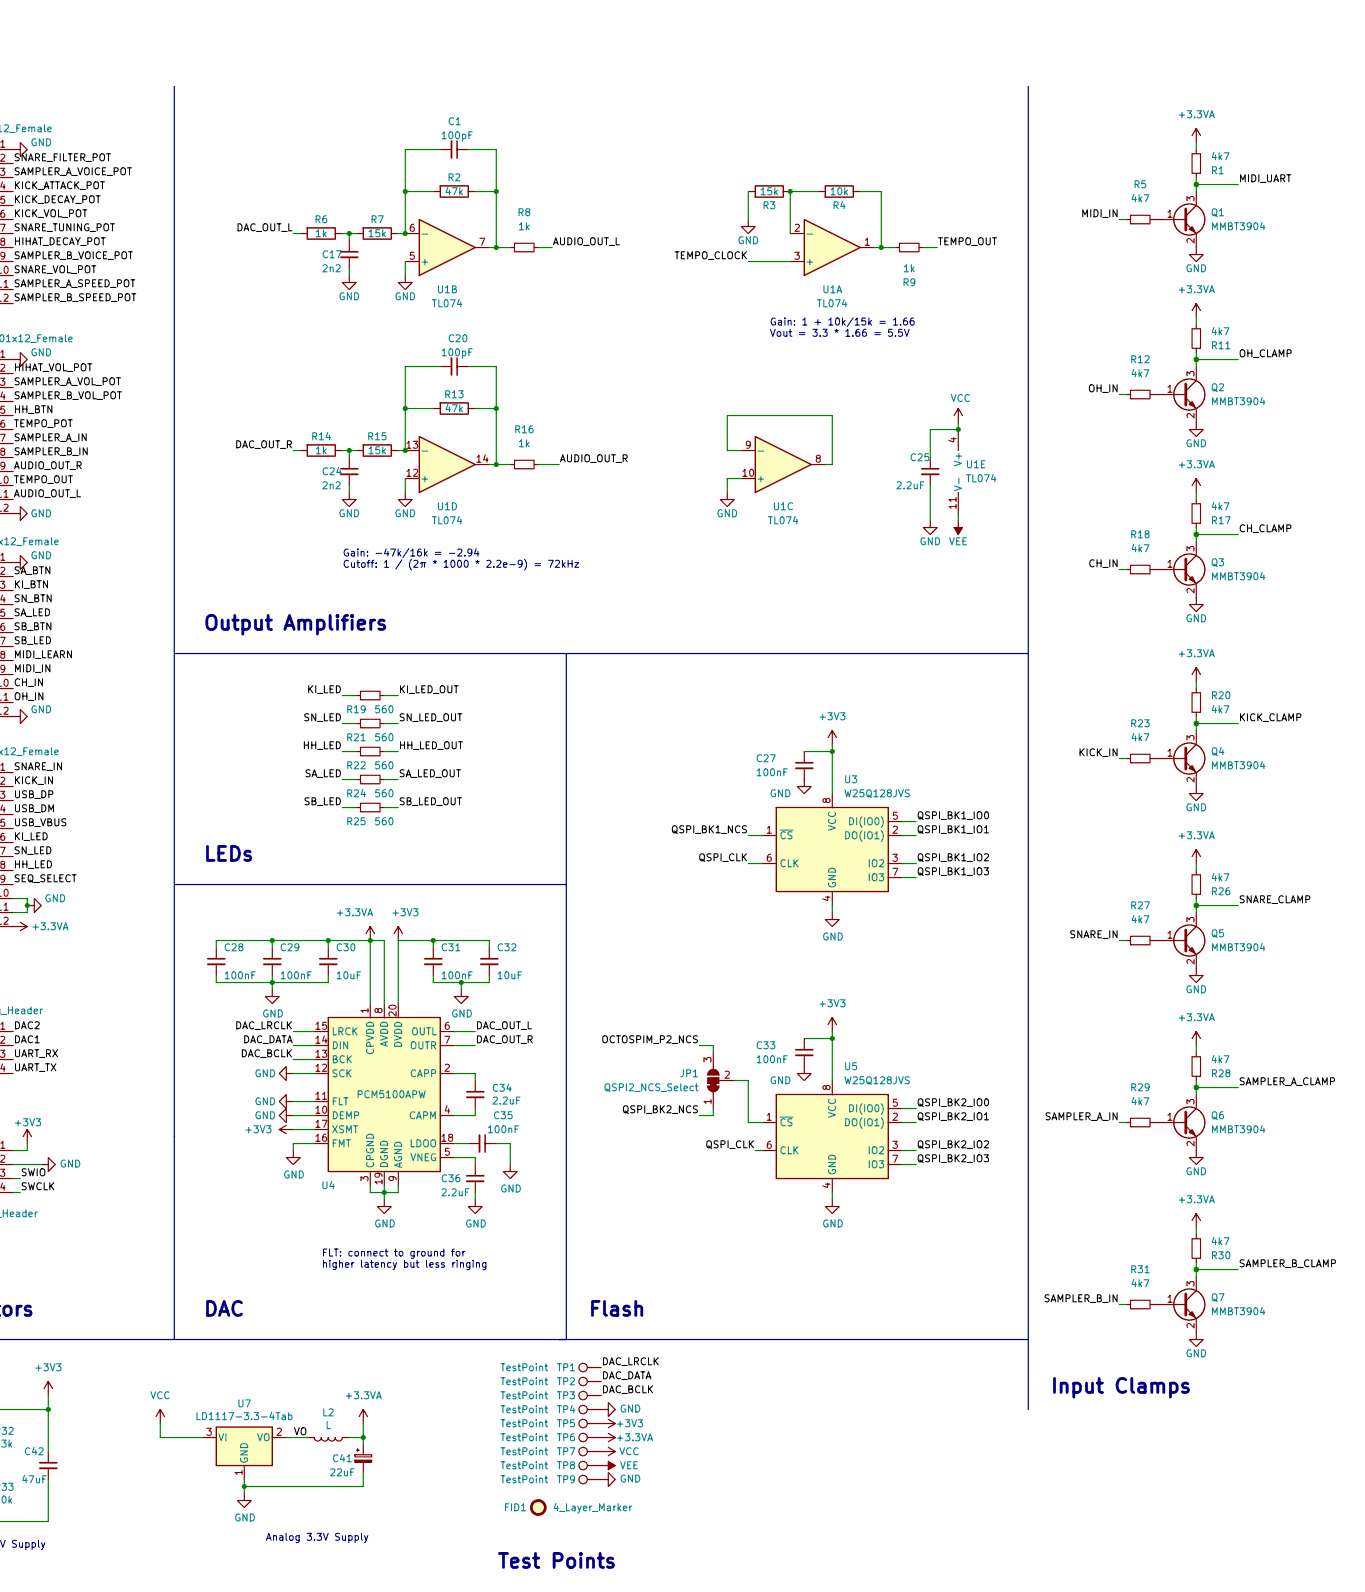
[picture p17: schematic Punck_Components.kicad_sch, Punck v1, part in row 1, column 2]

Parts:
C1, C20: 100pF; C_0603_1608Metric_Pad1.08x0.95mm_HandSolder; Part_Number C14858
C2: 4.7uF; C_0603_1608Metric_Pad1.08x0.95mm_HandSolder; Part_Number C14663
C3, C4, C5, C6, C7, C8, C9, C10, C11, C12, C13, C14, C15, C22, C27, C28, C29, C31, C33, C35: 100nF; C_0603_1608Metric_Pad1.08x0.95mm_HandSolder; Part_Number C14663
C16, C21: 1uF; C_0603_1608Metric_Pad1.08x0.95mm_HandSolder; Part_Number C14663
C17, C24: 2n2; C_0603_1608Metric_Pad1.08x0.95mm_HandSolder; Part_Number C1588
C18, C19, C25, C34, C36: 2.2uF; C_0603_1608Metric_Pad1.08x0.95mm_HandSolder; Part_Number C23630
C23, C26: 30pF; C_0603_1608Metric_Pad1.08x0.95mm_HandSolder; Part_Number C22397
C30, C32: 10uF; C_0805_2012Metric; Part_Number C15850
C37: 47uF; CP_Elec_5x5.8; Part_Number C134798
C38: 100nF; C_0805_2012Metric; Part_Number C57112
C39, C40: 10uF; C_0805_2012Metric; Part_Number C57112
C41, C43: 22uF; CP_Elec_4x5.8; Part_Number C134793
C42: 47uF; R_1206_3216Metric; Part_Number C57112
D1, D2: 1N5819; D_SOD-123; Part_Number C8598
FID1: 4_Layer_Marker; 4_Layer_Markers
J1, J2, J3, J4: Conn_01x12_Female; PinHeader_1x12_P2.54mm_Vertical
J5: Debug_Header; PinHeader_1x04_P2.54mm_Vertical
J6: SWD_Header; SWD_header
J7: Eurorack_10_pin_power; Eurorack_10_pin_header
JP1: QSPI2_NCS_Select; SolderJumper-3_P1.3mm_Bridged12_RoundedPad1.0x1.5mm
L1: 3.3uH; L_0806; Part_Number C326343
L2: L; L_0805_2012Metric; Part_Number C1046
Q1, Q2, Q3, Q4, Q5, Q6, Q7: MMBT3904; SOT-23; Part_Number C20526
R1, R5, R11, R12, R17, R18, R20, R23, R26, R27, R28, R29, R30, R31: 4k7; R_0603_1608Metric_Pad0.98x0.95mm_HandSolder; Part_Number C23162
R2, R13: 47k; R_0603_1608Metric_Pad0.98x0.95mm_HandSolder; Part_Number C25819
R3, R7, R15: 15k; R_0603_1608Metric_Pad0.98x0.95mm_HandSolder; Part_Number C25804
R4: 10k; R_0603_1608Metric_Pad0.98x0.95mm_HandSolder; Part_Number C25819
R6, R14: 1k; R_0603_1608Metric_Pad0.98x0.95mm_HandSolder; Part_Number C4190
R8, R9, R16: 1k; R_0603_1608Metric_Pad0.98x0.95mm_HandSolder
R10: 100k; R_0603_1608Metric; Part_Number C25803
R19, R21, R22, R24, R25: 560; R_0603_1608Metric_Pad0.98x0.95mm_HandSolder; Part_Number C23162
R32: 33k; R_0603_1608Metric_Pad0.98x0.95mm_HandSolder
R33: 10k; R_0603_1608Metric_Pad0.98x0.95mm_HandSolder
RESET1: SW_Push; SW_SPST_EVQQ2
TP1, TP2, TP3, TP4, TP5, TP6, TP7, TP8, TP9: TestPoint; 1.3mm_Test_Point
U1: TL074; SOIC-14_3.9x8.7mm_P1.27mm
U2: STM32H743ZITx; LQFP-144_20x20mm_P0.5mm; Part_Number C114408
U3, U5: W25Q128JVS; SOIC-8_5.23x5.23mm_P1.27mm
U4: PCM5100APW; SSOP-20_4.4x6.5mm_Pitch0.65mm_Round_Pads; Part_Number C131154
U6: TPS561201; SOT-23-6_Handsoldering
U7: LD1117-3.3-4Tab; SOT-223-3_TabPin2
Y1: 12MHz 20pF; Crystal_SMD_5032-2Pin_5.0x3.2mm; Part_Number C115962

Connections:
+3.3VA: C15.2, C16.2, C21.2, C22.2, C28.1, C29.1, C30.1, C41.1, J4.12, L2.1, R1.2, R11.2, R17.2, R20.2, R26.2, R28.2, R30.2, TP6.1, U2.32 (VREF+), U2.33 (VDDA), U4.1 (CPVDD), U4.8 (AVDD)
+3V3: C2.2, C3.2, C4.2, C5.2, C6.2, C7.2, C8.2, C9.2, C10.2, C11.2, C12.2, C13.2, C14.2, C27.1, C31.1, C32.1, C33.1, C42.1, J6.1, L1.2, R32.1, TP5.1, U2.6 (VBAT), U2.17 (VDD), U2.30 (VDD), U2.39 (VDD), U2.52 (VDD), U2.62 (VDD), U2.72 (VDD), U2.84 (VDD), U2.95 (VDD33_USB), U2.108 (VDD), U2.121 (VDD), U2.131 (VDD), U2.143 (PDR_ON), U2.144 (VDD), U3.8 (VCC), U4.17 (XSMT), U4.20 (DVDD), U5.8 (VCC)
+12V: D1.2 (A), J7.9, J7.10
-12V: D2.1 (K), J7.1, J7.2
/AUDIO_OUT_L: J2.11, R8.2
/AUDIO_OUT_R: J2.9, R16.2
/CB: C38.2, U6.6 (VBST)
/CH_CLAMP: Q3.3 (C), R17.1, U2.125 (PG10)
/CH_IN: J3.10, R18.1
/DAC1: J5.2, U2.40 (PA4)
/DAC2: J5.1, U2.41 (PA5)
/DAC_BCLK: TP3.1, U2.74 (PB13), U4.13 (BCK)
/DAC_DATA: TP2.1, U2.76 (PB15), U4.14 (DIN)
/DAC_LRCLK: TP1.1, U2.73 (PB12), U4.15 (LRCK)
/DAC_OUT_L: R6.2, U4.6 (OUTL)
/DAC_OUT_R: R14.2, U4.7 (OUTR)
/FB: R32.2, R33.1, U6.4 (VFB)
/HH_BTN: J2.5, U2.64 (PE11)
/HH_LED: J4.8, R22.1
/HH_LED_OUT: R22.2, U2.97 (PC7)
/HIHAT_DECAY_POT: J1.8, U2.42 (PA6)
/HIHAT_VOL_POT: J2.2, U2.47 (PB1)
/KICK_ATTACK_POT: J1.4, U2.34 (PA0)
/KICK_CLAMP: Q4.3 (C), R20.1, U2.115 (PD1)
/KICK_DECAY_POT: J1.5, U2.35 (PA1)
/KICK_IN: J4.2, R23.1
/KICK_VOL_POT: J1.6, U2.36 (PA2)
/KI_BTN: J3.3, U2.136 (PB6)
/KI_LED: J4.6, R19.1
/KI_LED_OUT: R19.2, U2.99 (PC9)
/MIDI_IN: J3.9, R5.1
/MIDI_LEARN: J3.8, U2.142 (PE1)
/MIDI_UART: Q1.3 (C), R1.1, U2.141 (PE0)
/OCTOSPIM_P2_NCS: JP1.3 (B), U2.127 (PG12)
/OH_CLAMP: Q2.3 (C), R11.1, U2.123 (PD7)
/OH_IN: J3.11, R12.1
/QSPI_BK1_IO0: U2.80 (PD11), U3.5 (DI(IO0))
/QSPI_BK1_IO1: U2.81 (PD12), U3.2 (DO(IO1))
/QSPI_BK1_IO2: U2.1 (PE2), U3.3 (IO2)
/QSPI_BK1_IO3: U2.82 (PD13), U3.7 (IO3)
/QSPI_BK1_NCS: U2.91 (PG6), U3.1 (~CS)
/QSPI_BK2_IO0: U2.58 (PE7), U5.5 (DI(IO0))
/QSPI_BK2_IO1: U2.59 (PE8), U5.2 (DO(IO1))
/QSPI_BK2_IO2: U2.60 (PE9), U5.3 (IO2)
/QSPI_BK2_IO3: U2.63 (PE10), U5.7 (IO3)
/QSPI_BK2_NCS: JP1.1 (A), U2.112 (PC11)
/QSPI_CLK: U2.48 (PB2), U3.6 (CLK), U5.6 (CLK)
/SAMPLER_A_CLAMP: Q6.3 (C), R28.1, U2.67 (PE14)
/SAMPLER_A_IN: J2.7, R29.1
/SAMPLER_A_SPEED_POT: J1.11, U2.45 (PC5)
/SAMPLER_A_VOICE_POT: J1.3, U2.27 (PC1)
/SAMPLER_A_VOL_POT: J2.3, U2.49 (PF11)
/SAMPLER_B_CLAMP: Q7.3 (C), R30.1, U2.68 (PE15)
/SAMPLER_B_IN: J2.8, R31.1
/SAMPLER_B_SPEED_POT: J1.12, U2.46 (PB0)
/SAMPLER_B_VOICE_POT: J1.9, U2.43 (PA7)
/SAMPLER_B_VOL_POT: J2.4, U2.50 (PF12)
/SA_BTN: J3.2, U2.137 (PB7)
/SA_LED: J3.5, R24.1
/SA_LED_OUT: R24.2, U2.85 (PD14)
/SB_BTN: J3.6, U2.128 (PG13)
/SB_LED: J3.7, R25.1
/SB_LED_OUT: R25.2, U2.86 (PD15)
/SEQ_SELECT: J4.9, U2.96 (PC6)
/SNARE_CLAMP: Q5.3 (C), R26.1, U2.117 (PD3)
/SNARE_FILTER_POT: J1.2, U2.26 (PC0)
/SNARE_IN: J4.1, R27.1
/SNARE_TUNING_POT: J1.7, U2.37 (PA3)
/SNARE_VOL_POT: J1.10, U2.44 (PC4)
/SN_BTN: J3.4, U2.135 (PB5)
/SN_LED: J4.7, R21.1
/SN_LED_OUT: R21.2, U2.98 (PC8)
/SWCLK: J6.4, U2.109 (PA14)
/SWIO: J6.3, U2.105 (PA13)
/TEMPO_CLOCK: U1.3 (+), U2.78 (PD9)
/TEMPO_OUT: J2.10, R9.2
/TEMPO_POT: J2.6, U2.53 (PF13)
/UART_RX: J5.3, U2.18 (PF6)
/UART_TX: J5.4, U2.19 (PF7)
/USB_DM: J4.4, U2.103 (PA11)
/USB_DP: J4.3, U2.104 (PA12)
/USB_VBUS: J4.5, U2.101 (PA9)
/VO: L2.2, U7.2 (VO)
/VSW: C38.1, L1.1, U6.2 (SW)
GND: C2.1, C3.1, C4.1, C5.1, C6.1, C7.1, C8.1, C9.1, C10.1, C11.1, C12.1, C13.1, C14.1, C15.1, C16.1, C17.2, C18.2, C19.2, C21.1, C22.1, C23.2, C24.2, C25.2, C26.2, C27.2, C28.2, C29.2, C30.2, C31.2, C32.2, C33.2, C35.1, C36.2, C37.2, C39.2, C40.2, C41.2, C42.2, C43.1, J1.1, J2.1, J2.12, J3.1, J3.12, J4.10, J4.11, J6.2, J7.3, J7.4, J7.5, J7.6, J7.7, J7.8, Q1.2 (E), Q2.2 (E), Q3.2 (E), Q4.2 (E), Q5.2 (E), Q6.2 (E), Q7.2 (E), R3.2, R10.1, R33.2, RESET1.2, TP4.1, TP9.1, U1.5 (+), U1.10 (+), U1.12 (+), U2.16 (VSS), U2.31 (VSSA), U2.38 (VSS), U2.51 (VSS), U2.61 (VSS), U2.83 (VSS), U2.94 (VSS), U2.107 (VSS), U2.120 (VSS), U2.130 (VSS), U3.4 (GND)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
unnamed: C1.1, R2.1, R8.1, U1.7
unnamed: C1.2, R2.2, R7.1, U1.6 (-)
unnamed: C17.1, R6.1, R7.2
unnamed: C18.1, U2.71 (VCAP1)
unnamed: C19.1, U2.106 (VCAP2)
unnamed: C20.1, R13.1, R16.1, U1.14
unnamed: C20.2, R13.2, R15.1, U1.13 (-)
unnamed: C23.1, U2.23 (PH0), Y1.2
unnamed: C24.1, R14.1, R15.2
unnamed: C26.1, U2.24 (PH1), Y1.1
unnamed: C34.1, U4.2 (CAPP)
unnamed: C34.2, U4.4 (CAPM)
unnamed: C35.2, U4.18 (LDOO)
unnamed: C36.1, U4.5 (VNEG)
unnamed: JP1.2 (C), U5.1 (~CS)
unnamed: Q1.1 (B), R5.2
unnamed: Q2.1 (B), R12.2
unnamed: Q3.1 (B), R18.2
unnamed: Q4.1 (B), R23.2
unnamed: Q5.1 (B), R27.2
unnamed: Q6.1 (B), R29.2
unnamed: Q7.1 (B), R31.2
unnamed: R3.1, R4.2, U1.2 (-)
unnamed: R4.1, R9.1, U1.1
unnamed: R10.2, U2.138 (BOOT0)
unnamed: RESET1.1, U2.25 (NRST)
unnamed: U1.8, U1.9 (-)
VCC: C25.1, C37.1, C39.1, C40.1, D1.1 (K), TP7.1, U1.4 (V+), U6.3 (VIN), U6.5 (EN), U7.3 (VI)
VEE: C43.2, D2.2 (A), TP8.1, U1.11 (V-)

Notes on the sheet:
Digital 3.3V Supply
Gain: 1 + 10k/15k = 1.66 Vout = 3.3 * 1.66 = 5.5V
ADC Pins -------- PA0 ADC1_INP16 PA1 ADC1_INP17 PA2 ADC12_INP14 PA3 ADC12_INP15 [PA4 ADC12_INP18 DAC] [PA5 ADC12_INP19 DAC] PA6 ADC12_INP3 PA7 ADC12_INP7 PB0 ADC12_INP9 PB1 ADC12_INP5 PC0 ADC123_INP10 PC1 ADC123_INP11 PC2 ADC123_INP12 [PC3_C ADC3_INP1] PC4 ADC12_INP4 PC5 ADC12_INP8 PF11 ADC1_INP2 P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
Gain: -47k/16k = -2.94 Cutoff: 1 / (2π * 1000 * 2.2e-9) = 72kHz
Microcontroller
Connectors
Analog 3.3V Supply
LED Pins -------- PC6-9: TIM3/TIM8 PD12-15: TIM4 PB4-5: TIM3 PB6-7: TIM4
LEDs
Power
Flash
DAC
Output Amplifiers
FLT: connect to ground for higher latency but less ringing
Test Points
Input Clamps

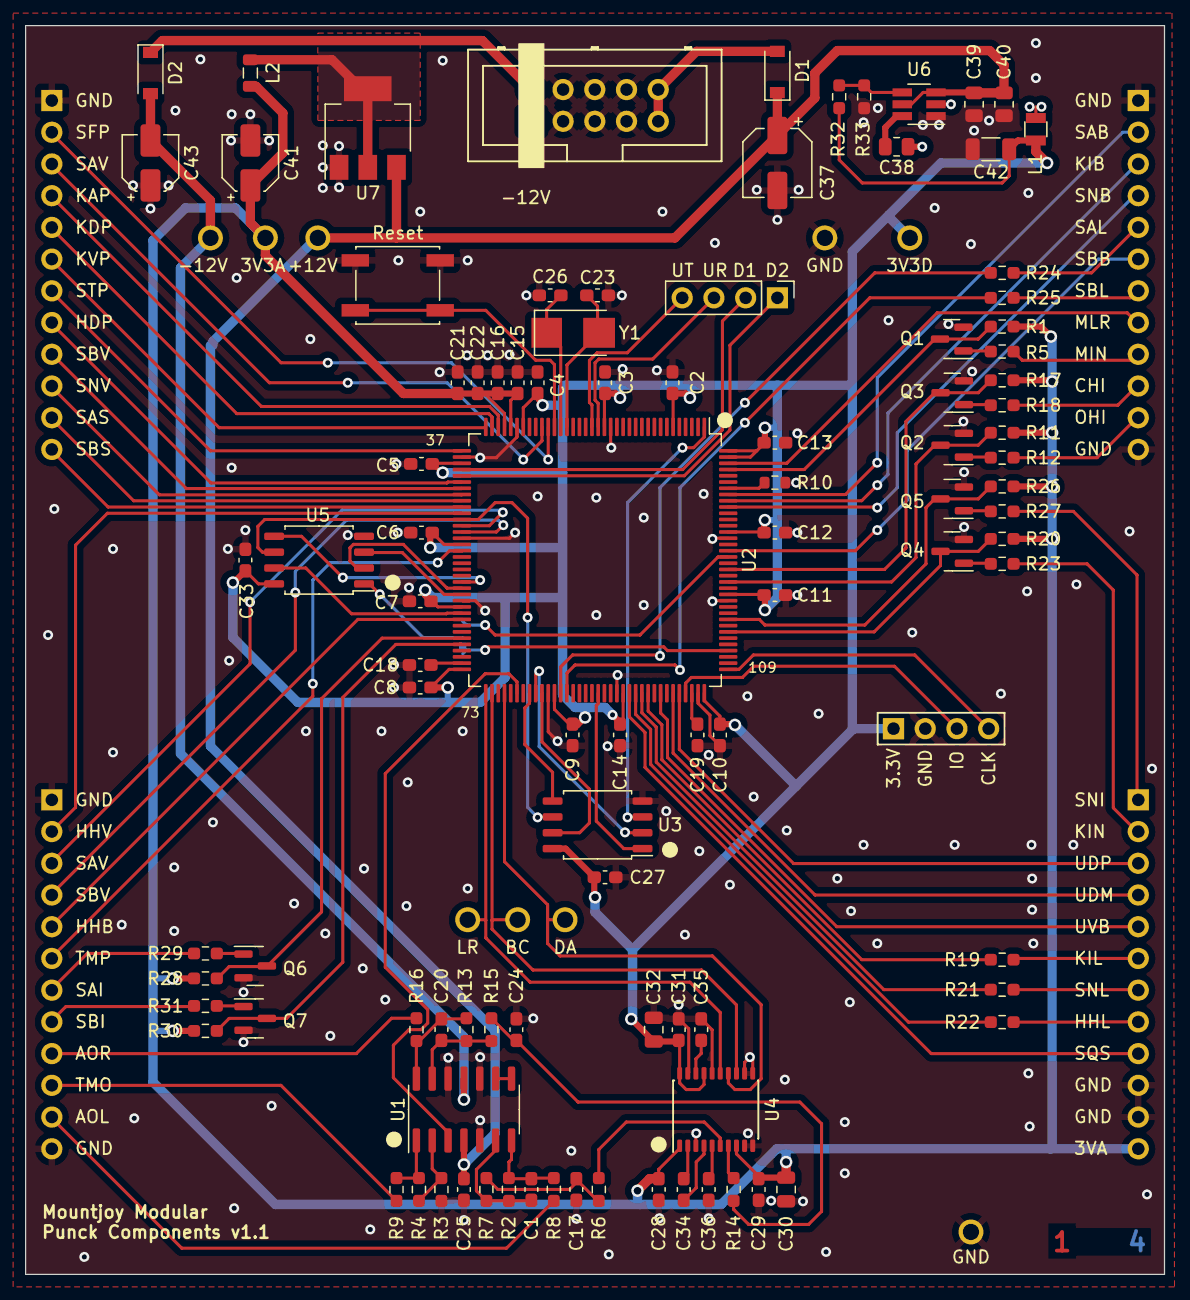
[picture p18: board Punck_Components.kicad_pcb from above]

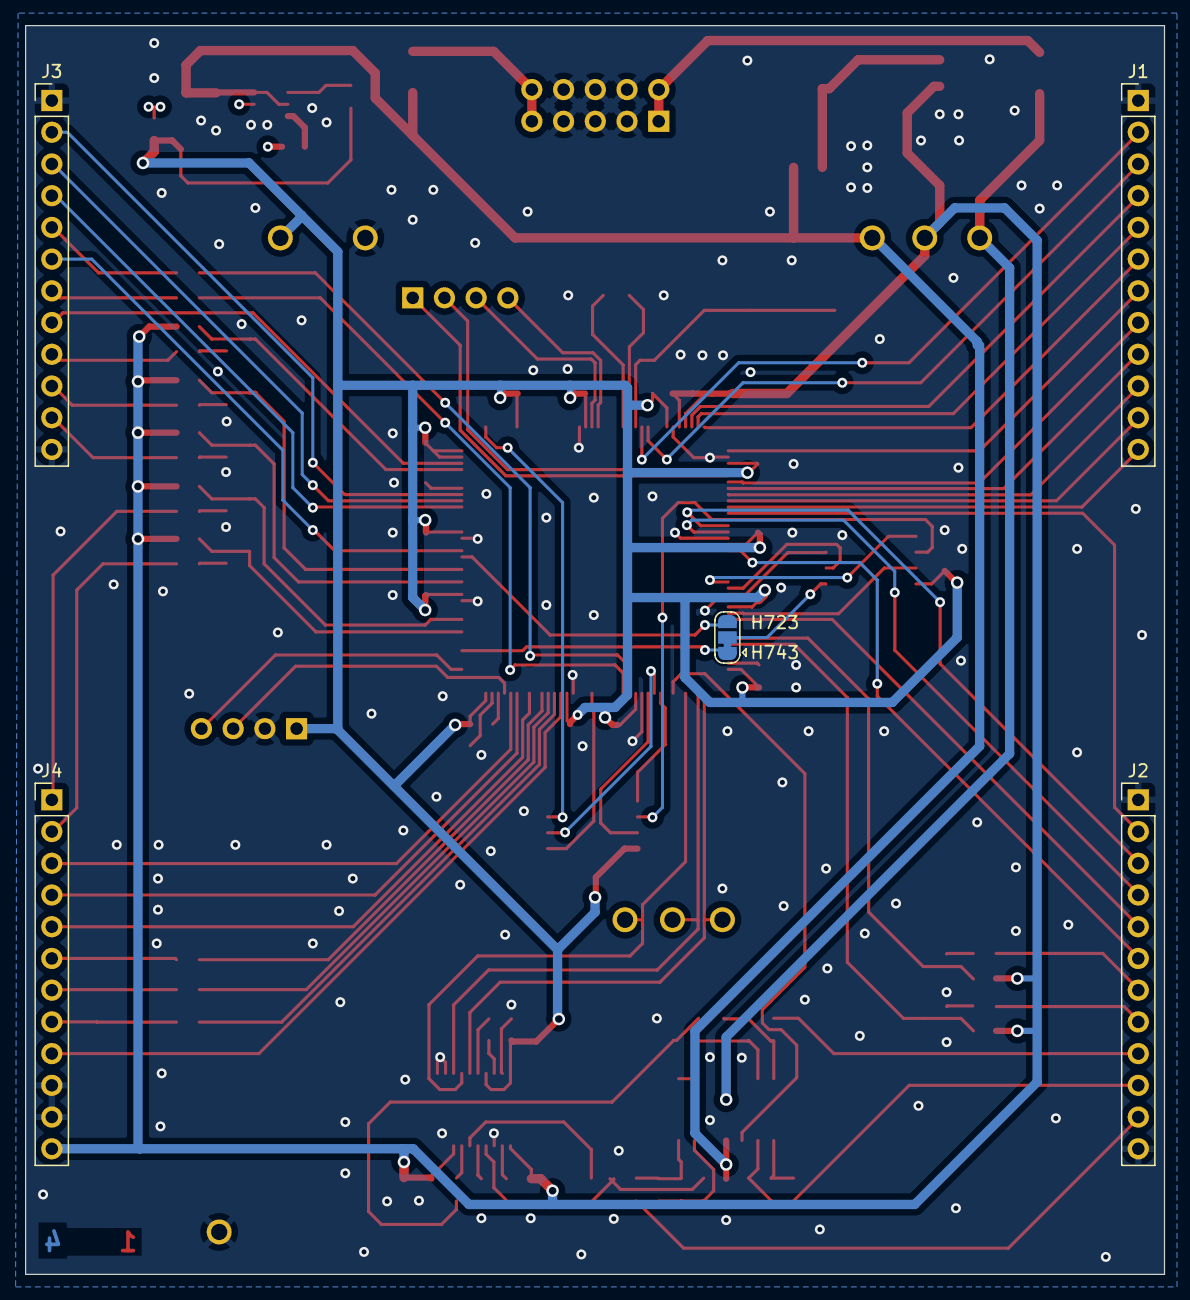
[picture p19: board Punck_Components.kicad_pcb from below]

Board: 4 copper layers, 91.2 x 100.0 mm, 114 parts (5 on the bottom side), 114 nets.

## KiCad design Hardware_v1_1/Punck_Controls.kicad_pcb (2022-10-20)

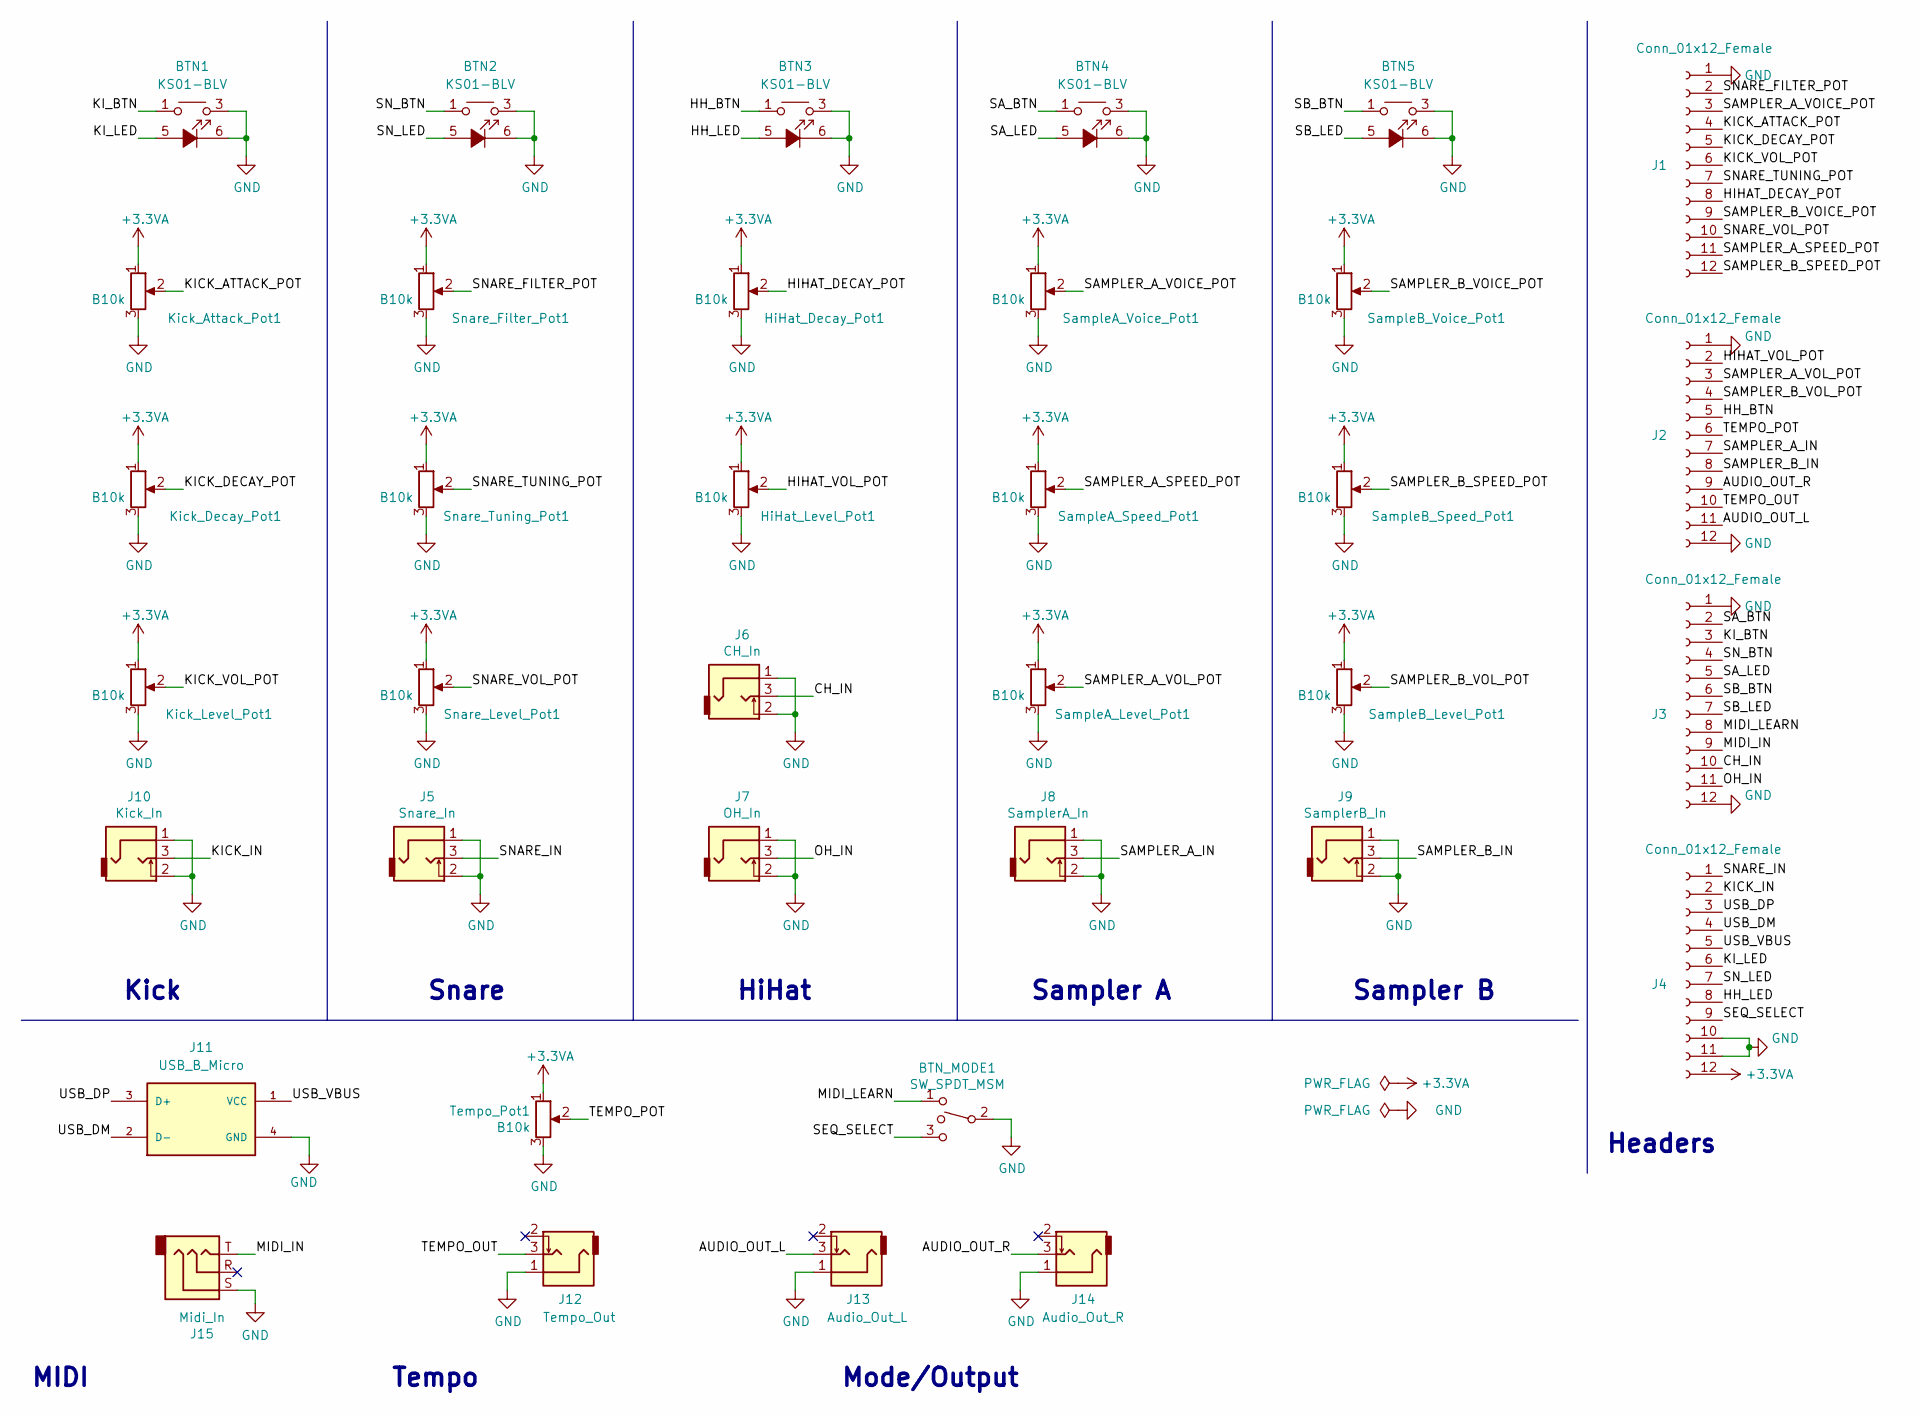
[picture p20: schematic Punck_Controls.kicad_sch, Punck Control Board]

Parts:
BTN1, BTN2, BTN3, BTN4, BTN5: KS01-BLV
BTN_MODE1: SW_SPDT_MSM; SPDT_SubMiniature_Aligned
HiHat_Decay_Pot1: B10k; Alpha_9mm_Potentiometer_Aligned
HiHat_Level_Pot1: B10k; Alpha_9mm_Potentiometer_Aligned
J1, J2, J3, J4: Conn_01x12_Female; PinHeader_1x12_P2.54mm_Vertical
J5: Snare_In; THONKICONN_hole
J6: CH_In; THONKICONN_hole
J7: OH_In; THONKICONN_hole
J8: SamplerA_In; THONKICONN_hole
J9: SamplerB_In; THONKICONN_hole
J10: Kick_In; THONKICONN_hole
J11: USB_B_Micro; USB_TE_1734517-1
J12: Tempo_Out; THONKICONN_hole
J13: Audio_Out_L; THONKICONN_hole
J14: Audio_Out_R; THONKICONN_hole
J15: Midi_In; Thonkiconn_Stereo-PJ366ST
Kick_Attack_Pot1: B10k; Alpha_9mm_Potentiometer_Aligned
Kick_Decay_Pot1: B10k; Alpha_9mm_Potentiometer_Aligned
Kick_Level_Pot1: B10k; Alpha_9mm_Potentiometer_Aligned
SampleA_Level_Pot1: B10k; Alpha_9mm_Potentiometer_Aligned
SampleA_Speed_Pot1: B10k; Alpha_9mm_Potentiometer_Aligned
SampleA_Voice_Pot1: B10k; Alpha_9mm_Potentiometer_Aligned
SampleB_Level_Pot1: B10k; Alpha_9mm_Potentiometer_Aligned
SampleB_Speed_Pot1: B10k; Alpha_9mm_Potentiometer_Aligned
SampleB_Voice_Pot1: B10k; Alpha_9mm_Potentiometer_Aligned
Snare_Filter_Pot1: B10k; Alpha_9mm_Potentiometer_Aligned
Snare_Level_Pot1: B10k; Alpha_9mm_Potentiometer_Aligned
Snare_Tuning_Pot1: B10k; Alpha_9mm_Potentiometer_Aligned
Tempo_Pot1: B10k; Alpha_9mm_Potentiometer_Aligned

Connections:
+3.3VA: HiHat_Decay_Pot1.1, HiHat_Level_Pot1.1, J4.12, Kick_Attack_Pot1.1, Kick_Decay_Pot1.1, Kick_Level_Pot1.1, SampleA_Level_Pot1.1, SampleA_Speed_Pot1.1, SampleA_Voice_Pot1.1, SampleB_Level_Pot1.1, SampleB_Speed_Pot1.1, SampleB_Voice_Pot1.1, Snare_Filter_Pot1.1, Snare_Level_Pot1.1, Snare_Tuning_Pot1.1, Tempo_Pot1.1
/AUDIO_OUT_L: J2.11, J13.3
/AUDIO_OUT_R: J2.9, J14.3
/CH_IN: J3.10, J6.3
/HH_BTN: BTN3.1, BTN3.2, J2.5
/HH_LED: BTN3.5 (A), J4.8
/HIHAT_DECAY_POT: HiHat_Decay_Pot1.2, J1.8
/HIHAT_VOL_POT: HiHat_Level_Pot1.2, J2.2
/KICK_ATTACK_POT: J1.4, Kick_Attack_Pot1.2
/KICK_DECAY_POT: J1.5, Kick_Decay_Pot1.2
/KICK_IN: J4.2, J10.3
/KICK_VOL_POT: J1.6, Kick_Level_Pot1.2
/KI_BTN: BTN1.1, BTN1.2, J3.3
/KI_LED: BTN1.5 (A), J4.6
/MIDI_IN: J3.9, J15.T
/MIDI_LEARN: BTN_MODE1.1, J3.8
/OH_IN: J3.11, J7.3
/SAMPLER_A_IN: J2.7, J8.3
/SAMPLER_A_SPEED_POT: J1.11, SampleA_Speed_Pot1.2
/SAMPLER_A_VOICE_POT: J1.3, SampleA_Voice_Pot1.2
/SAMPLER_A_VOL_POT: J2.3, SampleA_Level_Pot1.2
/SAMPLER_B_IN: J2.8, J9.3
/SAMPLER_B_SPEED_POT: J1.12, SampleB_Speed_Pot1.2
/SAMPLER_B_VOICE_POT: J1.9, SampleB_Voice_Pot1.2
/SAMPLER_B_VOL_POT: J2.4, SampleB_Level_Pot1.2
/SA_BTN: BTN4.1, BTN4.2, J3.2
/SA_LED: BTN4.5 (A), J3.5
/SB_BTN: BTN5.1, BTN5.2, J3.6
/SB_LED: BTN5.5 (A), J3.7
/SEQ_SELECT: BTN_MODE1.3, J4.9
/SNARE_FILTER_POT: J1.2, Snare_Filter_Pot1.2
/SNARE_IN: J4.1, J5.3
/SNARE_TUNING_POT: J1.7, Snare_Tuning_Pot1.2
/SNARE_VOL_POT: J1.10, Snare_Level_Pot1.2
/SN_BTN: BTN2.1, BTN2.2, J3.4
/SN_LED: BTN2.5 (A), J4.7
/TEMPO_OUT: J2.10, J12.3
/TEMPO_POT: J2.6, Tempo_Pot1.2
/USB_DM: J4.4, J11.2 (D-)
/USB_DP: J4.3, J11.3 (D+)
/USB_VBUS: J4.5, J11.1 (VCC)
GND: BTN1.3, BTN1.4, BTN1.6 (K), BTN2.3, BTN2.4, BTN2.6 (K), BTN3.3, BTN3.4, BTN3.6 (K), BTN4.3, BTN4.4, BTN4.6 (K), BTN5.3, BTN5.4, BTN5.6 (K), BTN_MODE1.2, HiHat_Decay_Pot1.3, HiHat_Level_Pot1.3, J1.1, J2.1, J2.12, J3.1, J3.12, J4.10, J4.11, J5.1, J5.2, J6.1, J6.2, J7.1, J7.2, J8.1, J8.2, J9.1, J9.2, J10.1, J10.2, J11.4 (GND), J12.1, J13.1, J14.1, J15.S, Kick_Attack_Pot1.3, Kick_Decay_Pot1.3, Kick_Level_Pot1.3, SampleA_Level_Pot1.3, SampleA_Speed_Pot1.3, SampleA_Voice_Pot1.3, SampleB_Level_Pot1.3, SampleB_Speed_Pot1.3, SampleB_Voice_Pot1.3, Snare_Filter_Pot1.3, Snare_Level_Pot1.3, Snare_Tuning_Pot1.3, Tempo_Pot1.3

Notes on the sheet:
Mode/Output
Sampler A
Tempo
Sampler B
HiHat
Snare
Kick
MIDI
Headers

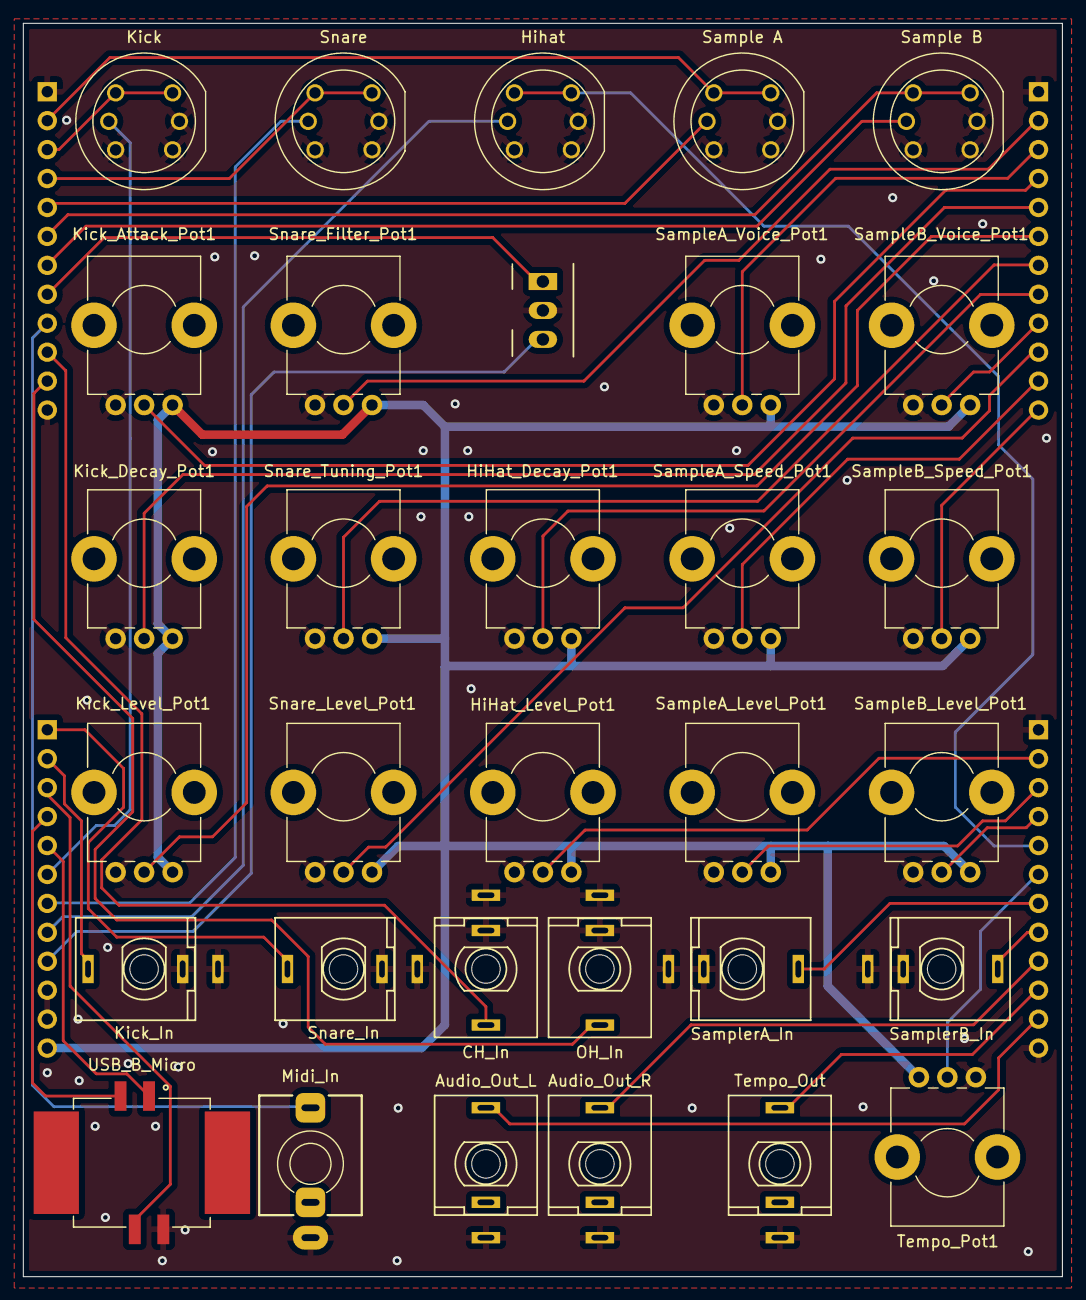
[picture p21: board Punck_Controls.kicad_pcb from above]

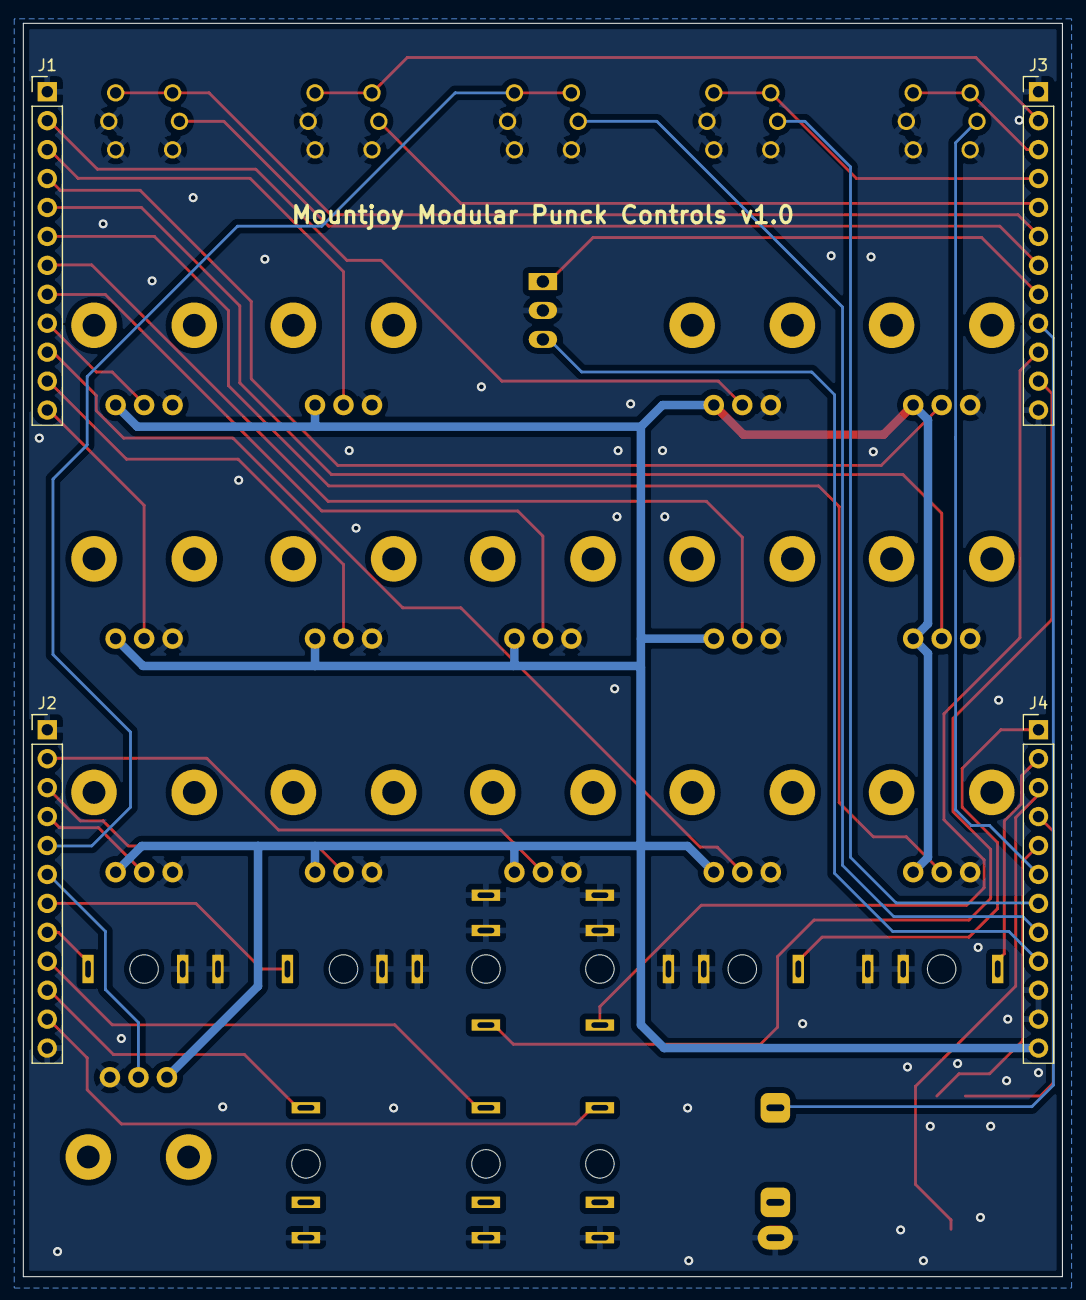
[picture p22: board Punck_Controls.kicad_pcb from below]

Board: 2 copper layers, 91.2 x 110.0 mm, 36 parts (4 on the bottom side), 42 nets.

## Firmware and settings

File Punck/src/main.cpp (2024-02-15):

#include "configManager.h"
#include "initialisation.h"
#include "USB.h"
#include "VoiceManager.h"
#include "FatTools.h"
#include "Reverb.h"


volatile uint32_t SysTickVal;		// 1 ms resolution
uint32_t i2sUnderrun = 0;				// Debug counter for I2S underruns
extern uint32_t SystemCoreClock;

// Create DMA buffer that need to live in non-cached memory area
volatile uint16_t __attribute__((section (".dma_buffer"))) ADC_array[ADC1_BUFFER_LENGTH + ADC2_BUFFER_LENGTH];

// Reverb delay lines are large so need to be placed in appropriate memory regions
Reverb __attribute__((section (".ram_d2_data"))) reverb;
float __attribute__((section (".ram_d1_data"))) reverbMixBuffer[94000];

// TODO:
// Sample panning (naming? web interface?)
// Performance updates
// Web editor: finish handling non-float values in config
// Sample playback does not account for samples stored in discontinuous memory locations


extern "C" {
#include "interrupts.h"
}


int main(void) {

	InitClocks();					// Configure the clock and PLL
	InitHardware();
	extFlash.Init();				// Initialise external QSPI Flash
	configManager.RestoreConfig();	// Restore configuration settings (voice config, MIDI mapping, drum sequences)
	usb.Init(false);				// Pass false to indicate hard reset
	InitI2S();						// Initialise I2S which will start main sample interrupts

	while (1) {
		usb.cdc.ProcessCommand();	// Check for incoming USB serial commands
		fatTools.CheckCache();		// Check if any outstanding cache changes need to be written to Flash
		voiceManager.IdleTasks();	// Check if filter coefficients need to be updated

#if (USB_DEBUG)
		if (uart.commandReady) {
			uart.ProcessCommand();
		}
#endif

	}
}

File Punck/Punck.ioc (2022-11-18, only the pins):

Mcu.UserName=STM32H743ZITx
PA11.Signal=USB_OTG_FS_DM
PA12.Signal=USB_OTG_FS_DP
PA4.Signal=ADCx_INP18
PA5.Signal=COMP_DAC12_group
PA9.Signal=USB_OTG_FS_VBUS
PB0.GPIO_Label=LD1 [Green Led]
PB0.Signal=GPIO_Output
PB12.Signal=I2S2_WS
PB13.Signal=I2S2_CK
PB14.GPIO_Label=LD3 [Red Led]
PB14.Signal=GPIO_Output
PB15.Signal=I2S2_SDO
PB2.Signal=QUADSPI_CLK
PC0.Signal=ADCx_INP10
PC11.Signal=QUADSPI_BK2_NCS
PC13.GPIO_Label=B1 [Blue PushButton]
PC13.Signal=GPIO_Input
PD11.Signal=QUADSPI_BK1_IO0
PD12.Signal=QUADSPI_BK1_IO1
PD13.Signal=QUADSPI_BK1_IO3
PE10.Signal=QUADSPI_BK2_IO3
PE2.Signal=QUADSPI_BK1_IO2
PE7.Signal=QUADSPI_BK2_IO0
PE8.Signal=QUADSPI_BK2_IO1
PE9.Signal=QUADSPI_BK2_IO2
PF6.Signal=UART7_RX
PF7.Signal=UART7_TX
PG6.Signal=QUADSPI_BK1_NCS

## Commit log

2022-07-01 Started adding QSPI initialisation
    [Punck_Components.kicad_pcb, Punck_Components.kicad_sch]
2022-07-05 Quad read uses alternate bytes to pad address; added printf to usb
2022-07-11 QSPI Flash driver: implemented multi-page writes and status polling
2022-07-18 Added debug function to use FatFS directory print
2022-07-23 Prevent interrupts during Flash cache flush as this was messing with writes
2022-07-26 Added tools to analyse WAV file header to populate sample table
2022-07-26 Added busy flag and led during sample writes
2022-07-28 Fixed some non-contiguous cluster handling
    [main.cpp]
2022-07-30 Improvements to performance of MSC handler
    Also debugging issue where I2S interrupts stop firing
    [initialisation.cpp, main.cpp]
2022-08-02 MDMA Transfer working in MSC Handler
    Still need to reorganize interrupt handler
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2022-08-04 Changed I2S interrupt handling and datasize to resolve channel flipping issue
    Also increased speed of QSPI from 700kHz to 6.25MHz
    [initialisation.cpp, samples.cpp]
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2022-08-05 USB refactoring; started adding support for varying sample playback speed
2022-08-05 Implemented ADC; added potentiometer control of sample speed
2022-08-08 Fixed USB issue mapping endpoints to classes; MSC, CDC and MIDI all working over USB
    [USB.cpp, USB.h, main.cpp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]
2022-08-12 USB class: fixes for class lookup from endpoint
    [NoteHandler.cpp, USB.cpp, USB.h]
2022-08-12 USB class creates endpoint to interface array; fixed issues with FAT table initialisation
    [USB.cpp, USB.h]
2022-08-12 Clean up of USB class fixes
    [USB.cpp, USB.h, main.cpp]
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2022-08-15 Serial MIDI working
    Fixed issues allowing A/B samples to be played simultaneously
    [Punck_Components.kicad_sch]
2022-08-15 Sample playback fixes; handle MIDI UART overrun
    Increased USB interrupt priority to try and prevent UART firing and causing issues
    [NoteHandler.cpp, USB.cpp, initialisation.cpp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]
2022-08-19 Kick and Samplers outputs mixed; added decay control to kick
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2022-08-21 Cleaned up filter code; testing timing of I2S interrupt to avoid double triggering
    [Filter.h, Kick.cpp, main.cpp]
2022-08-21 Note handler responsible for generating mixed output samples
2022-08-24 Further work on snare model; started adding velocity sensitivity
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2022-08-25 Added velocity sensitivity to kick and snare; fixed USB MIDI sysex
    Started adding USB MIDI web editor
    [Kick.cpp, NoteHandler.cpp, Snare.cpp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]
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2022-08-29 Fixed issue receiving long SysEx commands; more work on browser configuration
    [Filter.h, HiHat.cpp, HiHat.h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]
2022-09-03 Added band pass filter and test updates to hihat voice
2022-09-05 Hihat: Added some gentle low pass filtering and added decay control
2022-09-06 Added hihat noise decay setting
    [HiHat.cpp, HiHat.h]
2022-09-06 Hihat noise component in stereo
    [HiHat.cpp, HiHat.h]
2022-09-08 Added tempo control to sequencer and button debouncing
2022-09-13 Fixed issue validating samples with long header data
    [samples.cpp]
2022-09-15 Started adding option to select from sample list in sequence editor
2022-09-16 web editor: Samples can be selected for individual beats
2022-09-17 Web editor can automatically display currently playing bar
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2022-09-25 STarted PCB layout; ADC control updates
    [Punck_Components.kicad_pcb, Punck_Components.kicad_sch, Punck_Controls.kicad_sch]
2022-09-26 Rough Draft of Control PCB Done
    [Punck_Controls.kicad_pcb, Punck_Controls.kicad_sch]
2022-09-27 First draft of Controls PCB
    [Punck_Controls.kicad_pcb, Punck_Controls.kicad_sch]
2022-09-28 Added better handling for problems with flash device
    + temporarily lowered the speed of the QSPI flash as demo rig was glitching
    + added a diagnostic to get Flash manufacturer and device ID
    [Punck_Components.kicad_sch]
2022-09-29 Started component PCB
    [Punck_Components.kicad_pcb, Punck_Components.kicad_sch, Punck_Controls.kicad_sch]
2022-10-01 Component PCB Signal routing first draft
    [Punck_Components.kicad_pcb, Punck_Components.kicad_sch, Punck_Controls.kicad_pcb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]
2022-10-02 Power routing on component PCB
    [Punck_Components.kicad_pcb]
2022-10-02 More component routing
    [Punck_Components.kicad_pcb, Punck_Components.kicad_sch]
2022-10-04 Component PCB first draft
    [Punck_Components.kicad_pcb, Punck_Components.kicad_sch, Punck_Controls.kicad_pcb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]
2022-10-04 Started panel layout
    [Punck_Components.kicad_pcb, Punck_Controls.kicad_pcb, Punck_Panel.kicad_pcb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]
2022-10-05 Updated components on panel board
    [Punck_Components.kicad_pcb, Punck_Components.kicad_sch, Punck_Controls.kicad_pcb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]
2022-10-06 Rough panel layout
    [Punck_Components.kicad_pcb, Punck_Components.kicad_sch, Punck_Panel.kicad_pcb]
2022-10-06 Redesign of panel layout
    [Punck_Panel.kicad_pcb]
2022-10-06 Updated PCBs to match changes in panel; ground returns improved
    [Punck_Components.kicad_pcb, Punck_Components.kicad_sch, Punck_Controls.kicad_pcb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]
2022-10-06 More PCB tweaking
    [Punck_Components.kicad_pcb, Punck_Components.kicad_sch, Punck_Controls.kicad_pcb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]
2022-10-07 Added Logo to panel
    [Punck_Components.kicad_pcb, Punck_Components.kicad_sch, Punck_Panel.kicad_pcb]
2022-10-07 More PCB tweaks; rejigged bottom row of controls
    [Punck_Components.kicad_pcb, Punck_Components.kicad_sch, Punck_Controls.kicad_pcb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]
2022-10-08 Added test code to use PWM control on voice LEDs
    [Punck_Components.kicad_pcb, Punck_Components.kicad_sch, Punck_Controls.kicad_pcb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]
2022-10-16 Fixed incorrect pinout on transistors
    [Punck_Components.kicad_pcb, Punck_Components.kicad_sch]
2022-10-20 Final tweaking and v1 gerber creation; JLC order placed
    [Punck_Components-B_Cu.gbr, Punck_Components-B_Mask.gbr, Punck_Components-B_Paste.gbr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]
2022-10-21 Fixes to copper pour on L2 for v1 production
    [Punck_Components-B_Cu.gbr, Punck_Components-B_Mask.gbr, Punck_Components-B_Paste.gbr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]
2022-10-25 V1.1 Hardware updates; code refactoring and cleanup
    [Punck_Components-B_Cu.gbr, Punck_Components-B_Mask.gbr, Punck_Components-B_Paste.gbr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]
2022-10-26 Added workaround for CDC not working sending packets with size a multiple of 64
    [Filter.h, USB.cpp, USB.h]
2022-11-05 Started altering project to bring up v1 hardware
    [Punck_Components.kicad_pcb, Punck_Components.kicad_sch]
2022-11-08 Code updated to support v1 hardware
    Buttons and LEDs working; majority of ADCs tested; Serial MIDI working
2022-11-08 Updating sequence playing and MIDI learn switches
    All ADCs tested working
2022-11-09 Testing second Flash chip; started work on fixing FAT formatting
    [initialisation.cpp]
2022-11-10 Added support for 32 (inc float) and 8 bit samples
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2022-11-13 Open hat trigger working; triggers operate separately to note buttons
    Still need to address debouncing when multiple triggers/buttons activated simultaneously
2022-11-13 MIDI learn feature working correctly
    [VoiceManager.cpp, main.cpp]
2022-11-15 MIDI notes queued to play in main interrupt loop
    Solves problem of main loop interrupting a MIDI interrupt triggering a play
    [HiHat.cpp, Kick.cpp, Snare.cpp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]
2022-11-15 Fixed bug where changing sequences from web editor did not update LEDs
    [Sequencer.cpp, main.cpp]
2022-11-15 Fixed bugs updating web editor when switching sequences from module
2022-11-16 Fixed web editor hanging when no samples found
    [Snare.cpp, initialisation.cpp, initialisation.h]
2022-11-16 Updated configManager; auto-save on MIDI learn
    Also added save config option to web editor and use LEDs to show when config save is happening
2022-11-17 Added tempo clock out functionality
    [Punck_Components.kicad_sch]
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2022-11-18 Fixed bug receiving UART data
    [main.cpp, uartHandler.cpp]
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2022-11-23 Split configuration descriptors in USB class
    Additional work to try and resolve issue with USB disconnect/reconnect not working
    [Punck_Components.kicad_sch]
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2022-11-28 Preparation for attempted USB restart fix
    [initialisation.h, main.cpp]
2022-11-29 USB working after reconnect; fixed FAT caching issues
    [USB.cpp, USB.h, main.cpp]
2022-12-01 Refined claps model;
    - Updated MIDI mapping to handle claps and toms
    - Tweaks to Band Pass filter updating
    - Added timing information for each voice to serial console
2022-12-02 Fixed bug extracting long file names overwriting filter settings
    [HiHat.cpp, Kick.cpp, Sequencer.cpp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]
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2022-12-08 Fixed bug getting volume from sample name
    Added more detailed timing information
    [VoiceManager.cpp, reverb.h, samples.cpp]
2022-12-08 Filter update changes; Increased QSPI speed
    - Hi hat filter calculated as Idle Task
    - Voice filters recalculated when voices not playing so ready for next hit
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2022-12-10 Moved band pass filter functionality to main filter class
    - Adjusted snare settings to tighter sound
    - Cleaned up filter class to remove calculations using normalised value a0 = 1.0f
    [Filter.h, Snare.cpp, USB.cpp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]
2023-09-14 Update to kicad 7
    [Punck_Components.kicad_sch]
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2024-05-28 Added JLC assembly data
    [BOM-Punck_Components.csv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]
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2024-05-28 Updated crystal to 12 MHz
    [BOM-Punck_Components.csv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]
2025-03-03 Fixed bug using random mode where only one sample in bank
    [samples.cpp]
2025-03-10 Fixed USB enumerating on Linux
    [USB.cpp]
